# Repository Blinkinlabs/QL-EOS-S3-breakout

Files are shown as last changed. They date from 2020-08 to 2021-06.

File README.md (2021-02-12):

# QL-EOS-S3-breakout

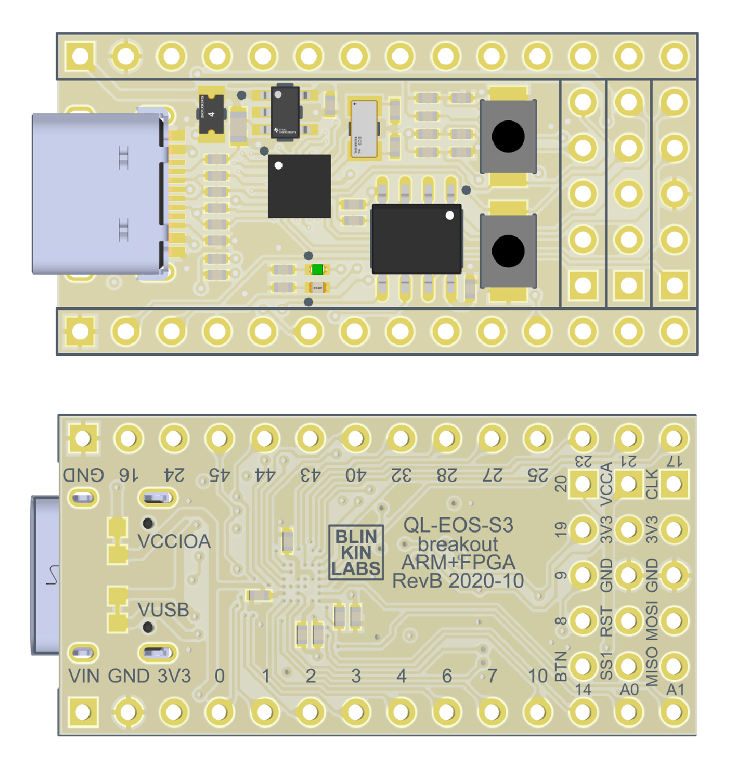
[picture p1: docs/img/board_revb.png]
Pinout guide)


A breadboard-friendly, low part count breakout board for the QuickLogic EOS-S3 ARM/FPGA IC.

Details are in the [Users Guide](https://blinkinlabs.github.io/QL-EOS-S3-breakout/).

Want one? [Sign up](https://docs.google.com/forms/d/e/1FAIpQLSfQSrQm0ui1FXlJnKaiTJos3fivZU6aR2ZEdR-fBZTCpYlu7w/viewform) to be notified when they're available!

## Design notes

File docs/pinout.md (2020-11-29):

# Pinout and Peripherals

## Pinout

Compared to a normal microcontroller, the pins on the QL-EOS-S3 SoC are a little goofy. Similar to a normal microcontroller, it has some hardware GPIO pins that are attached to the ARM core, along with standard peripherals such as UART, and SPI busses, along with an analog port. Unlike a normal microcontroller, however, most of the pins are not connected to the ARM core at all! Instead, they are all connected to the FPGA core, and can be used by writing your own peripherals in Verilog.

Here is a map of all of the fixed pins on the board:

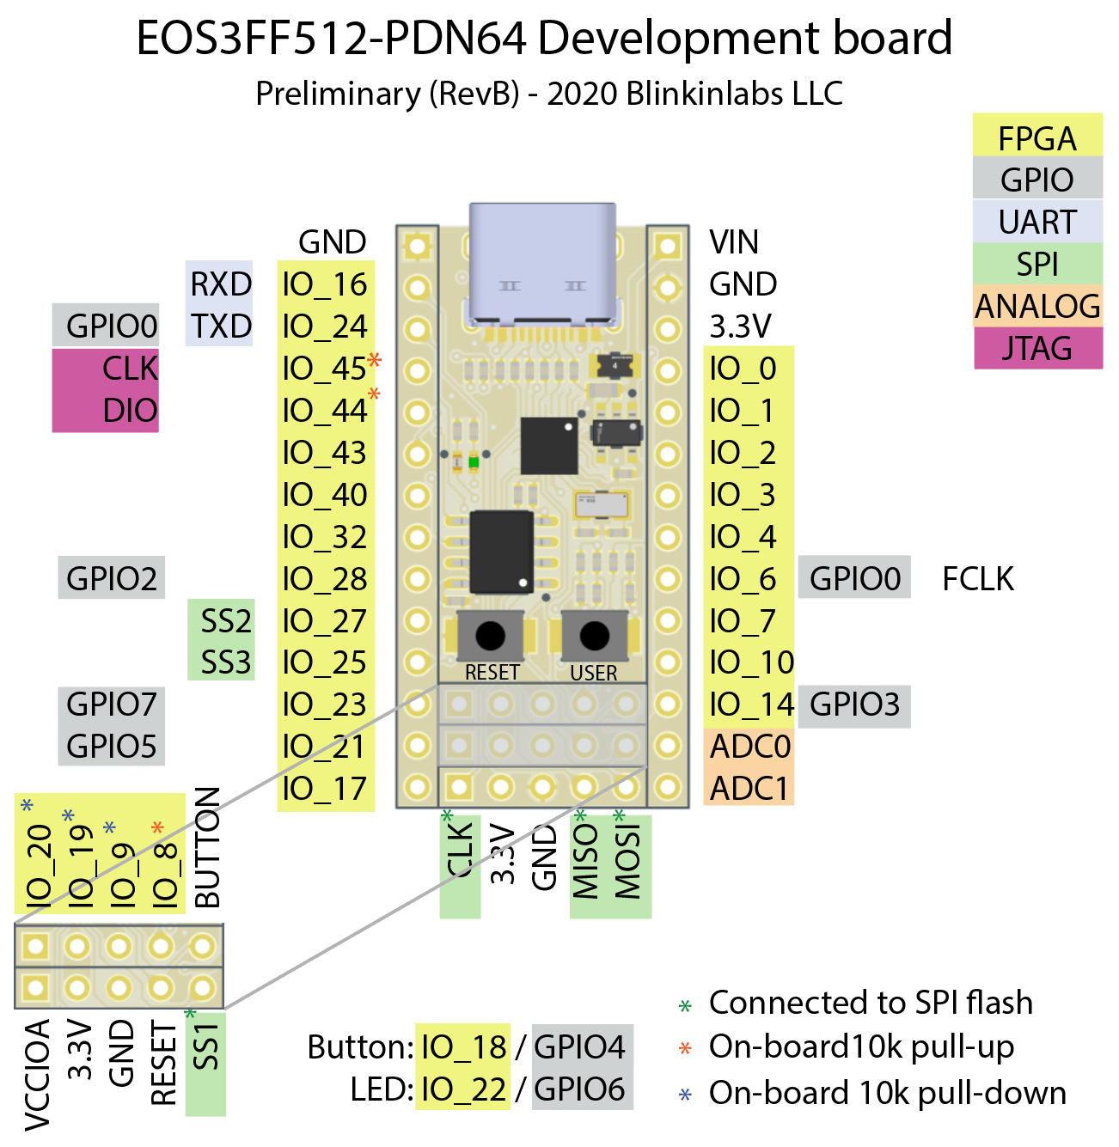
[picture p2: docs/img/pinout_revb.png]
Pinout


All of the pins on the right and left sides of the boards can be used freely. Note that the two JTAG pins (IO_44 and IO_45 on RevB) have on-board pullup resistors to the 3.3V line. The pins in the center section are also possible to use use, however they affect how the SoC boots.

### Use with caution: SPI pins

The SPI pins (CLK, MOSI, MISO, and SS1) are attached to the on-board SPI flash. The CLK, MOSI, and MISO pins can be safely shared with other SPI devices, as long as they do not interfere with the boot process.

### Use with caution: Bootstrap pins

IO_8, IO_9, IO_19, and IO_20 are avaiable as general-purpose IO, however they have 10k pull-down resistors connected to them, and their values have to be logic low at boot time for the microcontroller to turn on correctly.

## Hardware GPIO

The arm core is able to control 8 of the pins (marked GPIO0..7 in the pinout diagram). Here are the steps to use them:

### Step 1: Check that the GPIO is assigned to the correct pin

Each GPIO can be connected to one of two hardware pins. The pin selection is stored in IOMUX_IO_REG_SEL, at 0x40004D60. Here is a table of the available GPIO pin mappings, and the proper one for the breakout board:

| GPIO | Default pin | Alternate pin | Breakout board pin | Notes |
| ---  | --- | --- | --- | --- |
| 0 | IO_6 | IO_24 | IO_6 | |
| 1 | IO_9 | IO_26 | IO_9 | Bootstrap pin |
| 2 | IO_11 | IO_28 | IO_28 | Breakout board uses alternate pin |
| 3 | IO_14 | IO_30 | IO_14 | |
| 4 | IO_18 | IO_31 | IO_18 | Connected to USER BUTTON |
| 5 | IO_21 | IO_36 | IO_21 | |
| 6 | IO_22 | IO_38 | IO_22 | Connected to STATUS LED |
| 7 | IO_23 | IO_45 | IO_23 | |

Only GPIO2 needs to be assigned to the alternate pin, so the following can be used to fully configure the GPIO pin assignments:

    machine.mem32[0x40004D60] = (1<<2)

### Step 2: Configure the pin for GPIO mode

Now that we know the pin that the GPIO is assigned to, the next step is to configure it for GPIO mode, as either an input or output. To do this, write to the IOMUX_PADxx_CTRL register associated with the pad. The address is: 0x40004C00 + 4*(pad number)

Example: Configure pin IO_18 as a GPIO input with pull-up enabled:

    machine.mem32[0x40004C00 + (18*4)] = (0x3<<0) | (0x0<<3) | (1<<8) | (1<<5) | (1<<11) | (0x1<<6)

Example: Configure pin IO_22 as a GPIO output with 4mA drive strength:

    machine.mem32[0x40004C00 + (22*4)] = (0x3<<0) | (0x0<<3) | (1<<8)

### Step 3: Read (or write) to the GPIO

To read from a gpio, use the register MISC_IO_INPUT at 0x40005100. For instance, to read the value of GPIO4 (user button):

    print((machine.mem32[0x40005100] >> 4) & 0x1)

To write a GPIO value, us the register MISC_IO_OUTPUT at 0x40005104. For instance, to set GPIO6 (status led) high:

    machine.mem32[0x40005104] |= (1 << 6)

### Interrupts

Each GPIO pin can be used as a level or edge sensitive interrupt. All GPIO pins share a single interrupt vector.
 
TODO: Example for using interrupts

### Example GPIO library

Here is a barebones GPIO library, written in Micropython:

    class GPIO:
      IOMUX_BASE = 0x40004C00
      IOMUX_IO_REG_SEL = 0x40004D60
      MISC_IO_INPUT = 0x40005100
      MISC_IO_OUTPUT = 0x40005104
      def __init__(self):
        # Configure GPIO pin selects for breakout board
        # Note: Only GPIO2 uses alternate pin setting
        machine.mem32[self.IOMUX_IO_REG_SEL] = (1<<2)
      def write(self, gpio, val):
        if val == 0: # Low
          machine.mem32[self.MISC_IO_OUTPUT] &= ~(1 << gpio)
        else: # High
          machine.mem32[self.MISC_IO_OUTPUT] |= (1 << gpio)
      def read(self, gpio):
        return ((machine.mem32[self.MISC_IO_INPUT] >> gpio) & 0x01)
      def pinmode(self, gpio, mode):
        pads = (6,9,11,14,18,21,22,23)
        if mode == 'input':
          machine.mem32[self.IOMUX_BASE + pads[gpio]*4] = (0x3<<0) | (0x0<<3) | (1<<8) | (1<<5) | (1<<11)
        elif mode == 'input_pullup':
          machine.mem32[self.IOMUX_BASE + pads[gpio]*4] = (0x3<<0) | (0x0<<3) | (1<<8) | (1<<5) | (1<<11) | (0x1<<6)
        elif mode == 'output':
          machine.mem32[self.IOMUX_BASE + pads[gpio]*4] = (0x3<<0) | (0x0<<3) | (1<<8)

And to use it:

    gpio=GPIO()
    gpio.pinmode(6,'output')
    gpio.write(6,1) # turn on LED
    gpio.pinmode(4,'input_pullup')
    gpio.read(4) # read button input

## UART

_TODO_

## SPI Master

SPI Master 1 is connected to the ARM, and available for use. Unfortunately, the technical reference manual is very light on the details, and the SDK drivers are buggy and poorly documented. It appears to be an instantion of a Synopsys DesignWire IP 'DW_apb_ssi'. Because this a commonly used IP block, there are some references to similar hardware:

* [Linux driver](https://github.com/ilbers/linux/blob/master/drivers/spi/spi-dw.h)

_TODO_

## Analog to digital controller

_TODO_

## FPGA

The FPGA is the swiss army knife of peripherals

### Clocks

There are 3 input clocks from the ARM to the FPGA:

| Clock | Name | Max frequency | Notes |
| --- | --- | --- | --- |
| C16 | Sys_Clk0 | ? | General purpose |
| C21 | Sys_Clk1 | ? | General purpose |
| C02 | Sys_Pclk | ? | SPI master APB bus clock (?) |

Sys_Clk0 and Sys_Clk1 are 'general purpose' clocks. Both are fed from dedicated clocks, so configuring them should not intefere with any other ARM peripherals. They can be driven by either the high or low speed system clocks, with a divisor from 0-512. The technical reference manual specifies a default maximum speed of 10MHz, however speeds up to the system clock (72MHz) appear to function well.

Sys_Pclk is fed from C02, which is shared with some other ARM peripherals. It is also available for use, but reconfiguring it might cause problems.

There are 2 output clocks from the FPGA to the ARM:

| Clock | Name | Max frequency | Usage |
| --- | --- | --- | --- |
| C40 | WB_CLK | 10 Mhz | Fabric to Wishbone clock |
| C41 | Sys_Pkfb_Clk | 10 MHz | Fabric to PKFB (packet fifo) clock |

Both of these clocks are special purpose, and should be configured if you are planning to use their associated peripherals.

### IO pads

The FPGA can control all of the IO pads, including a direction function. However, the pads must first be configured by the ARM processor, for both driving source and I/O control functions.

Some of the pads are special clock inputs (TODO: which ones?)

### SPI Master

The FPGA is supposed to be able to interface with the SPI master, for some reason. It's not clear how to do this, or what the intended use case is.

### Communicating with the FPGA

To get the best use out of your FPGA designs, you'll want to talk to them from the ARM core. Here are some of the ways to do so.

#### AHB <-> wishbone bridge

The easiest way to talk to the FPGA is through the AHB<->wishbone bus, which directly maps into the ARM memory space.

| Block | M4 base address | Size |
| --- | --- | --- |
| Fabric (FPGA) | 0x4002_0000 | 128KB |

Transactions must be intiated by the ARM. For bulk data transfer, consider the Packet FIFO interface.

#### SDMA

_TODO_

#### Packet FIFO

There are 4 fifo blocks:

| Block | M4 base address | Size |
| --- | --- | --- |
| RAMFIFO0 (FPGA) | 0x4001_8000 | 4KB |
| RAMFIFO1 (FPGA) | 0x4001_9000 | 4KB |
| RAMFIFO2 (FPGA) | 0x4001_A000 | 4KB |
| RAMFIFO3 (FPGA) | 0x4001_B000 | 4KB |

_TODO_

#### Interrupts

There are 4 interrupt sources from the FPGA to the ARM.

| Intr Num | NVIC Intr | Address | Exception | Priority | Comments |
| --- | --- | --- | --- | --- | --- |
| 20 | 4 | 0x50 | Fabric | Message 0-7 (programmable) | SoC WIC interrupts |

FB_0_INTR, FB_1_INTR, FB_2_INTR, FB_3_INTR

## Other peripherals (I2C, I2S, PDM, FFE, Sensor Manager)

The datasheet and technical reference talk about some other useful peripherals, such as I2C, I2S, and PDM. Unfortunately, these peripherals seem to be attached to the Sensor Manager, and thus not directly accessable to the ARM part. It's unclear if the Sensor Manager is present in the version of the SoC that we have. The Flex Fusion Engine (FFE) is also mentioned, but is likely not enabled in the part variant that we have without some trickery.

Fortunately, this is the kind of task that the FPGA is perfect for. For instance, if you want an I2C bus, or ten, you can design them using Verilog, then use them directly from the ARM core. You're free to make the best possbile peripherals!

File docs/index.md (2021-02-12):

# QL-EOS-S3-breakout

Pinout guide

A breadboard-friendly, low part count breakout board for the QuickLogic EOS-S3 ARM/FPGA IC.

The goals of this project are:

* Low-cost, minimum viable ARM+FPGA design that is breadboard compatable
* Footprint, power, UART pin compatibility with Teensy 3.2.
* All pins on Bank A placed in a group, because they can have their IO voltage set with a reference
* Bootstrap, SPI flash, and reset pins placed in non-breadboardable location to avoid inadvertant interference with application circuit
* Pins with multiple IO functions preferred over FPGA only pins
* Pins in understandable (ascending) order by FPGA IO number, when possible

See the [release PDF](https://raw.githubusercontent.com/Blinkinlabs/QL-EOS-S3-breakout/main/releases/2020-10-06_ql-eos-s3-breakout_RevB.pdf) for the schematic.

Want one? [Sign up](https://forms.gle/7uMRd7YTaTRd96Ph6) to be notified when they are available!

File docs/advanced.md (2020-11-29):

# Advanced topics

## Reprogramming the SPI flash

### Introduction
The EOS-S3 SoC does not have internal nonvolatile memory, so it boots from an external SPI flash. The breakout board has a bootloader pre-installed in the flash memory, which can be used to program the device using it's USB port. However, if the bootloader becomes corrupted for whatever reason, it can be useful to restore the whole SPI flash.

To do this, you'll need a [Teensy](https://www.pjrc.com/store/teensy32.html) with the [spiflash](https://github.com/osresearch/spiflash) firmware loaded.

First, some technical details. This is the flash memory layout that the quickfeather bootloader is expecting:

|Item |Status |Start | Size | End |Start | Size | End |
|----- |---|---:| ---:| ---:  |---:| ---: | ---:|
|bootloader |Used |0x0000_0000| 0x0001_0000| 0x0000_FFFF | 0  | 65,536 |  65,536 |
|bootfpga CRC |Used |0x0001_0000| 8| 0x0001_0007 | 65,536  | 8 |  65,544 |
|appfpga CRC |Future |0x0001_1000| 8| 0x0001_1007 | 69,632  | 8 |  69,640 |
|appffe CRC |Future |0x0001_2000| 8| 0x0001_2007 | 73,728  | 8 |  73,736 |
|M4app CRC |Used |0x0001_3000| 8| 0x0001_3007 | 77,824  | 8 |  77,832 |
|bootloader CRC |Used |0x0001_4000| 8| 0x0001_4007 | 81,920  | 8 |  81,928 |
|bootfpga |Used |0x0002_0000| 0x0002_0000| 0x0003_FFFF | 131,072 | 131,072 | 262,144 |
|appfpga |Future |0x0004_0000| 0x0002_0000| 0x0005_FFFF | 262,144 | 131,072 | 393,216 |
|appffe |Future |0x0006_0000| 0x0002_0000| 0x0007_FFFF | 393,216 | 131,072 | 524,288 |
|M4app |Used |0x0008_0000| 0x0006_E000| 0x000E_DFFF | 524,288 | 450,560 | 974,848 |

The hardware in the SoC only cares about the first section, which contains the bootloader. When it comes out of reset, configuration logic in the SoC reads 32 bits of data from the SPI flash location 0x120, which contains a device ID, the size of the bootloader image, and the desired SPI clock setting. If these are valid, the configuration logic then copies the bootloader into the device SRAM, and then starts the ARM processor.

Once it starts, the bootloader displays a prompt on the UART pins, then waits 5 seconds. If the user button is pressed during these 5 seconds, then it loads the bootfpga image into the FPGA, which allows the user to reprogram the device using the TinyFPGA programmer. If the button is not pressed within 5 seconds, the bootloader attempts to load the user program from the SPI flash into SRAM. It then verifies that the CRC makes (TODO: Does it actually do this?), and if it does, reconfigures the ARM to point to that code, to enter the user program.

The TLDR here is that if we want to write a raw image to the flash, we'll need at least the bootloader, bootloader CRC, bootfpga, andd bootfpga CRC sections to be present. For extra points, we can also preinstall a user app by filling the M4app and M4app CRC sections.

### Step 1: Build the bootloader
First, let's build the bootloader:

    cd ~/ql-eos-s3/qorc-sdk/bl_apps/bl_bootloader/GCC_Project
    make

_TODO: what sets up the 0x120 offset in the bootloader binary?_

### Step 2: Make a flash image
A tool to build a suitable image is included in the [bl apps](https://github.com/Blinkinlabs/bl_apps/blob/main/tools/build_flash_image.py). Using it with the default options will grab the bootloader binary image that we just compiled above, as well as a (for now) precompiled appfpga image:

    cd ~/ql-eos-s3/qorc-sdk/bl_apps/tools
    python3 build_flash_image.py
    added section:bootloader at:0x00000000 size:38228 crc:0x555d0a3e
    added section:bootfpga at:0x00020000 size:75960 crc:0x82fc1983
    Wrote 0xee000 bytes to image.bin

This should create a file called 'image.bin', which we can then load on the SPI flash chip, starting at offset 0.

### Step 3: Flash it
Connect the Teensy to the dev board like so. Be sure to short the 'RST' pin on the board to 'GND', to prevent the SoC from booting:

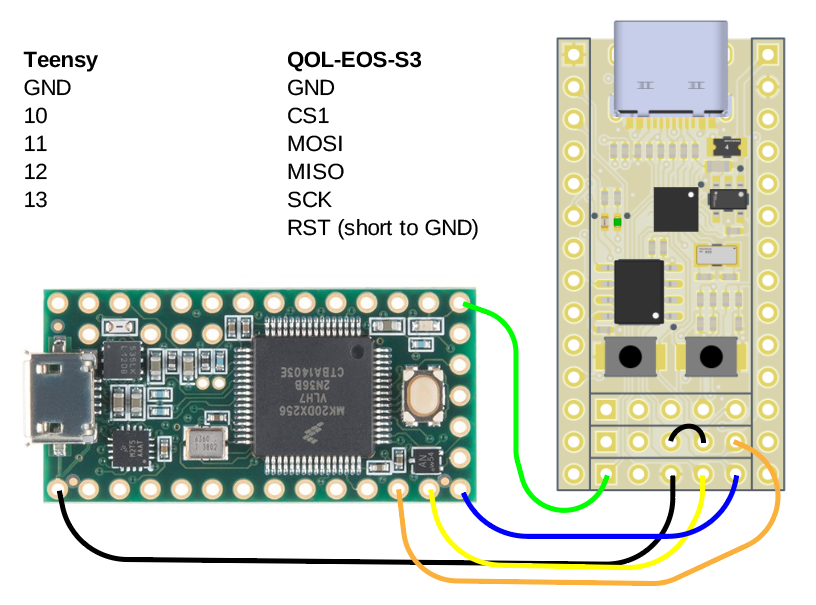
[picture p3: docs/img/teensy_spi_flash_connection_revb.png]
Teensy flash diagram


_TODO: text version of the pin table_

Next, connect both the Teensy and the board to your computer using USB. Use your favorite serial terminal to connect to the Teensy. Issue the 'i' command to check if the SPI flash can be identified:

    i
    C84015C8

_Note: The device ID for the flash on your board may differ, this is for the 2MB version_

Now, tell the Teensy that we want to write EE000 bytes to the SPI flash, starting at offset 0. If the flash image was a different length, use that instead:

    u0 EE0000
    G 00000000 EE0000

_Note: The 'u' will not be echoed to the terminal_

Exit the serial terminal, and then use the PV command to write the image:

    pv image.bin > /dev/ttyACM0

Now, detach the Teensy, then remove the jumper between RST and GND to boot flash image.

## Set the IO pins in Bank A to a different reference voltage
### Introduction
If you need to interface with a device that uses a different logic voltage than 3.3V, it is possible to set the reference voltage for the pins on Bank A.

### Step 1: Cut the VCCIOA trace on the back of the board
On the back side of the board, cut the short copper trace in the middle of the 'VCCIOA' pad. This will disconnect the VCCIOA power line from the on-board 3.3V regulator:
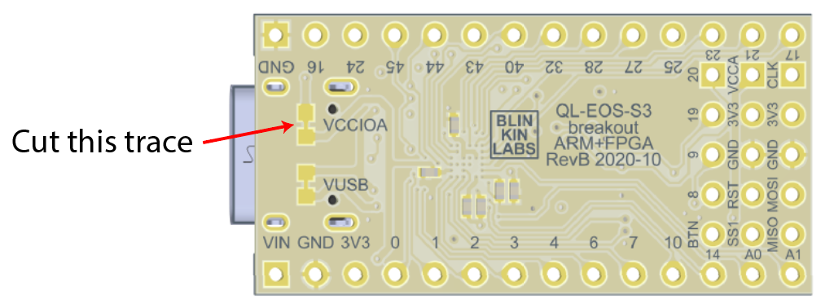
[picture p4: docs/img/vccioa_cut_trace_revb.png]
Cut the VCCIO trace


### Step 2: Provide a 1.71 - 3.6V reference on the VCCA pin
Once the trace has been cut, you'll need to connect an external voltage to the header pin marked 'VCCA'. Then, all of the pins on the right-hand side of the board will be referenced to the external supply:
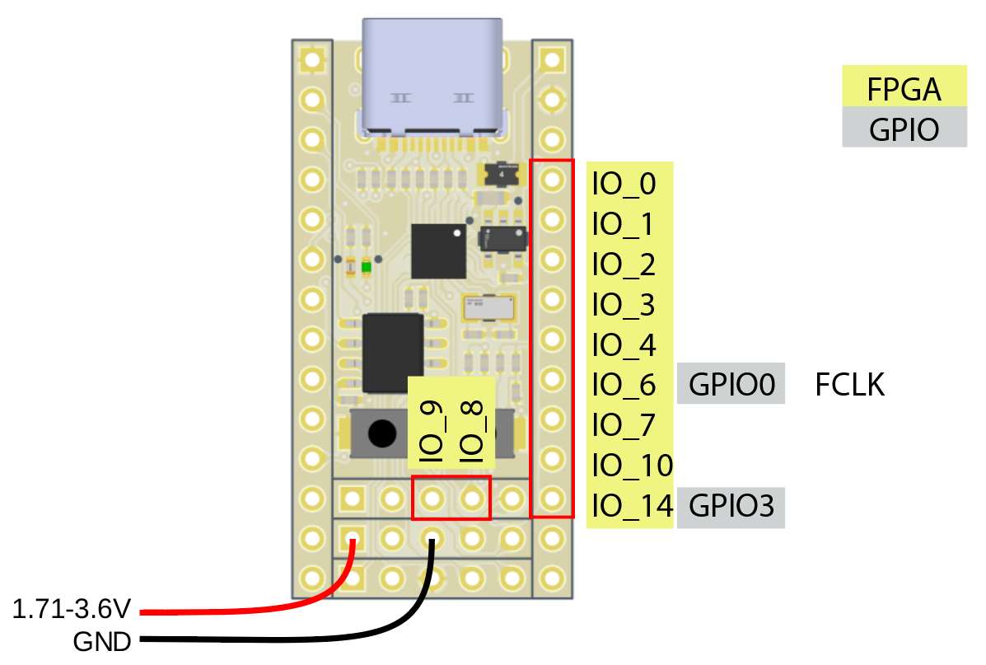
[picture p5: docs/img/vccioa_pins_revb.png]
VCCIOA pins


_Note: The datasheet specifies a range of 1.71-3.6V for safe operation_

## Attach a JTAG debugger
_TODO_

Using JTAG with the RevB board reuqires pulling up both IO_8 and IO_9, and supplying a clock to FCLK. Additionally, the 10k pullups on SWD and SCK may not be present, and would need to be added externally. A future revision will use an alternate JTAG pin mapping, to allow it to be used with the on-board oscillator.

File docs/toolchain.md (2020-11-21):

# Toolchain Setup

## Introduction
This is based on [Quickfeather getting started](https://github.com/QuickLogic-Corp/qorc-sdk#toolchain). There are instructions there for compiling from source.

## Prerequisites
Some prerequisites for a Debian / Ubuntu environment:

    sudo apt install build-essential
    sudo apt remove modemmanager
    sudo usermod -a -G dialout $USER

_Note: If you just added your user to dialout, log out and then back in again to apply the new membership_

Let's attempt to contain everything in a single directory:

    export INSTALL_DIR="$HOME/ql-eos-s3"
    mkdir $INSTALL_DIR
    cd $INSTALL_DIR

## ARM toolchain
First up, get ARM GCC:

    wget https://developer.arm.com/-/media/Files/downloads/gnu-rm/9-2020q2/gcc-arm-none-eabi-9-2020-q2-update-x86_64-linux.tar.bz2
    tar xvjf gcc-arm-none-eabi-9-2020-q2-update-x86_64-linux.tar.bz2 -C $INSTALL_DIR

    export PATH=$INSTALL_DIR/gcc-arm-none-eabi-9-2020-q2-update/bin/:$PATH

## FPGA toolchain
Then Symbiflow:

    wget 'https://github.com/QuickLogic-Corp/quicklogic-fpga-toolchain/releases/download/v1.3.0/Symbiflow_v1.3.0.gz.run'
    bash Symbiflow_v1.3.0.gz.run

    export PATH="$INSTALL_DIR/install/bin:$INSTALL_DIR/install/bin/python:$PATH"
    source "$INSTALL_DIR/conda/etc/profile.d/conda.sh"
    conda activate

And the TinyFPGA bootloader:

    git clone --recursive https://github.com/QuickLogic-Corp/TinyFPGA-Programmer-Application.git

    pip3 install pyserial
    pip3 install tinyfpgab

_Note: Make sure to activate conda in the previous step before using pip3 to install the python eggs_

## SDK
Now for the SDK and Blinkinlabs exmaples:

    git clone --recursive https://github.com/QuickLogic-Corp/qorc-sdk.git

    cd qorc-sdk
    git clone https://github.com/Blinkinlabs/bl_apps.git

# Default enviromnet
To make the tools available in your default environment, add the following to your .bashrc:

    # ARM gcc toolchain
    export PATH=$HOME/ql-eos-s3/gcc-arm-none-eabi-9-2020-q2-update/bin/:$PATH

    # FPGA toolchain for ql-eos-s3
    export INSTALL_DIR="$HOME/ql-eos-s3"
    export PATH="$HOME/ql-eos-s3/install/bin:$HOME/ql-eos-s3/install/bin/python:$PATH"
    source "$HOME/ql-eos-s3/conda/etc/profile.d/conda.sh"
    conda activate

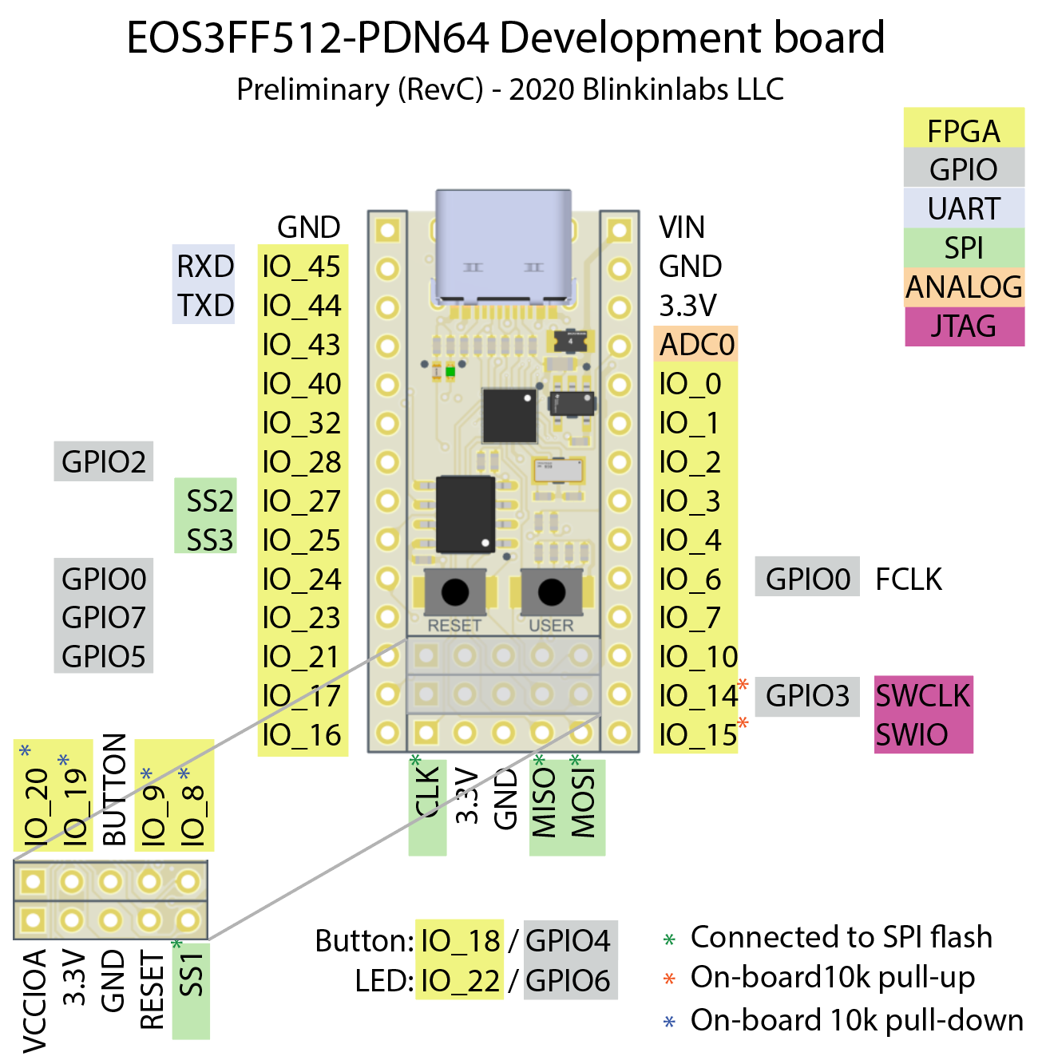
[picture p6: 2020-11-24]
docs/img/pinout_revc.png

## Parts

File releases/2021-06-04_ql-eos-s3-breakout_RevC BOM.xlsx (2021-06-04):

Designator | Comment | Manufacturer | PartNumber | Digi-Key Part Number | LCSC PartNumber | Description | Pins | Quantity | Model:Footprint | Case/Package
C1, C2, C5, C6 | 4.7uF | Murata Electronics North America | GRM155R60J475ME47D | 490-5915-1-ND |  | CAP CER 4.7UF 6.3V X5R 0402 | 2 | 4 |  | 0402
C3, C4 | 12pF | Murata Electronics North America | GRM1555C1E120GA01D | 490-8169-1-ND |  | CAP CER 12PF 25V NP0 0402 | 2 | 2 |  | 0402
C7, C8, C9, C10, C11 | 0.10uF | Murata Electronics North America | GRM152R61A104ME19D | 490-10009-1-ND |  | CAP CER 0.1UF 10V X5R 0402 | 2 | 5 |  | 0402
C12 | 4.7uF | Murata Electronics North America | GRM188R61A475KE15D | 490-10477-1-ND |  | CAP CER 4.7UF 10V X5R 0603 | 2 | 1 |  | 0603
DS1 | SML-P12PTT86 | Rohm |  |  |  | LED GREEN CLEAR 1006 SMD | 2 | 1
DS2 | SMLP12BC7TT86 | Rohm |  |  |  | LED BLUE CLEAR 1006 SMD | 2 | 1
F1 | MF-PSMF050X-2 | Bourns Inc. |  |  |  | PTC RESET FUSE 6V 500MA 0805 | 2 | 1
J1 | TYPE-C-31-M-12 | HRO | TYPE-C-31-M-12 |  |  | USB Connector TYPE-C-31-M-12 Female 16P SMD | 12 | 1 | USB Connector TYPE-C-31-M-12 Female 16P SMD
P1, P2 | Header 14 |  |  |  |  | Header, 14-Pin | 14 | 2 | Connector; Header; 14 Position
P3, P4, P5 | Header 5 |  |  |  |  | Header, 5-Pin | 5 | 3 | Connector; Header; 5 Position
R1, R2 | 5.1k | Panasonic Electronic Components | ERJ-2GEJ512X | P5.1KJCT-ND |  | RES SMD 5.1K OHM 5% 1/10W 0402 | 2 | 2 |  | 0402
R5, R8, R9, R22 | 1.5k | Panasonic Electronic Components | ERJ-2GEJ152X | P1.5KJCT-ND |  | RES SMD 1.5K OHM 5% 1/10W 0402 | 2 | 4 |  | 0402
R6, R7 | 22 | Panasonic Electronic Components | ERJ-2GEJ220X | P22JCT-ND |  | RES SMD 22 OHM 5% 1/10W 0402 | 2 | 2 |  | 0402
R10, R12, R13, R16, R17, R20, R21 | 10k | Panasonic Electronic Components | ERJ-2GEJ103X | P10KJCT-ND |  | RES SMD 10K OHM 5% 1/10W 0402 | 2 | 7 |  | 0402
SW1, SW2 | TS-1185 | XKB | TS-1185 |  |  | Tact Switch, 3x4mm, no alignment pin, turtle style | 2 | 2 | 3x4x2mm Tact Switch, no alignment pin
U1 | QL-EOS-S3 | QuickLogic Corporation | QL-EOS-S3 |  |  | QuickLogicEOS S3 Ultra Low Power multicore MCU | 64 | 1 | BGA, 64-Leads, Body 3.50x3.50mmx0.80mm, Pitch 0.40mm
U2 | TLV73333PDBVR | Texas Instruments |  |  |  | IC REG LINEAR 3.3V 300MA SOT23-5 | 5 | 1
U3 | GD25Q16CTIG | Gigadevice | GD25Q16CTIG |  |  | 16M-bit Serial Flash, 256 Bytes per programmable page, standard, dual, quad SPI | 8 | 1 | SOP, 8-Leads, Body 4.90x3.85mm, Pitch 1.27mm, IPC Medium Density
Y1 | ECS-.327-12.5-34B-TR |  |  |  |  | CRYSTAL 32.7680KHZ 12.5PF SMD | 2 | 1 |  | SMD/SMT

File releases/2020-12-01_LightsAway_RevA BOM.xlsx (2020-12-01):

Designator | Comment | Manufacturer | PartNumber | Digi-Key Part Number | LCSC PartNumber | Description | Pins | Quantity | Model:Footprint | Case/Package
C1, C2, C3 | 10uF | Murata Electronics North America | GRM21BR61C106ME15L | 490-6474-1-ND |  | CAP CER 10UF 16V X5R 0805 | 2 | 3 |  | 0805
J1, J2, J3, J4, J5, J6, J7, J8 | S4B-PH-SM4-TB(LF)(SN) | JST | S4B-PH-SM4-TB(LF)(SN) |  |  | CONN HEADER SMD R/A 4POS 2MM | 6 | 8 | CONN HEADER SMD R/A 4POS 2MM
J9 | Power | Phoenix Contact | 1751248 |  |  | TERM BLK 2POS SIDE ENT 3.5MM PCB | 2 | 1 | TERM BLK 2POS SIDE ENT 3.5MM PCB
J10 | TFP09-2-12B | Unknown/Generic | TFP09-2-12B |  |  | Micro SD Card Connector | 13 | 1 | Micro SD Card Connector
J11 | FTDI |  |  |  |  | Header, 6-Pin | 6 | 1 | Connector; Header; 6 Position
U1, U3 | SN74HCT245PWR | Texas Instruments |  |  |  | Octal Bus Transceivers With 3-State Outputs, PW0020A, LARGE T&R | 20 | 2 | SOP, 20-Leads, Body 6.6x4.5mm, Pitch 0.65mm, IPC High Density
U2 | BL-EOS-BREAKOUT-REVC | Blinkinlabs | QL-EOS-S3-Breakout |  |  |  | 33 | 1

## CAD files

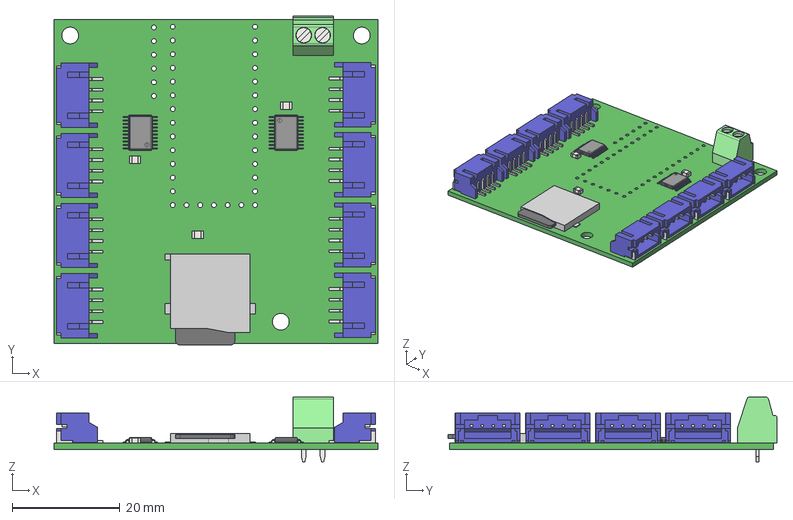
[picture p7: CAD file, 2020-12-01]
releases/2020-12-01_LightsAway_RevA.step
60.0 x 60.9 x 12.0 mm
bohrloch.1 x 2
MKDS_1-2-3_5
BODY_MTC20 x 2
LEAD_MTC20 x 40
TFP09-2-12B_v2
S4B-PH-SM4-TB x 8
Extruded x 9

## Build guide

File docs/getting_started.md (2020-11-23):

# Get Started

## Introduction
The QL-EOS-S3 board is a unique, low-cost microcontroller with a built-in FPGA.

## What you need
Hardware:

* [QL-EOS-S3 breakout board](https://github.com/Blinkinlabs/QL-EOS-S3-breakout)
* USB-C cable
* [3.3V FTDI cable](https://www.sparkfun.com/products/9717) (or other USB-serial converter)
* (optional) [Teensy 3.2](https://www.pjrc.com/store/teensy32.html), for restoring the SPI flash.
* (optional) ARM SWD adapter, such as the [Black magic probe](https://1bitsquared.com/products/black-magic-probe)

Software:

* ARM GCC toolchain, to compile code for the Cortex M4 processor
* Symbiflow toolchain, for generating FPGA bitstreams
* The QORC Software Development Kit
* Blinkinlabs example projects

## Installation

### Step 1: Install the toolchain
Follow the [toolchain setup](toolchain.md) instructions

### Step 2: Build an example project
Test a project that uses both the ARM and FPGA toolchains:

    cd ~/ql-eos-s3/qorc-sdk/bl_apps/bl_helloworldhw/GCC_Project
    make

### Step 3: Connect to the board
Connect your board to your computer using a USB cable. Next, connect an FTDI cable:

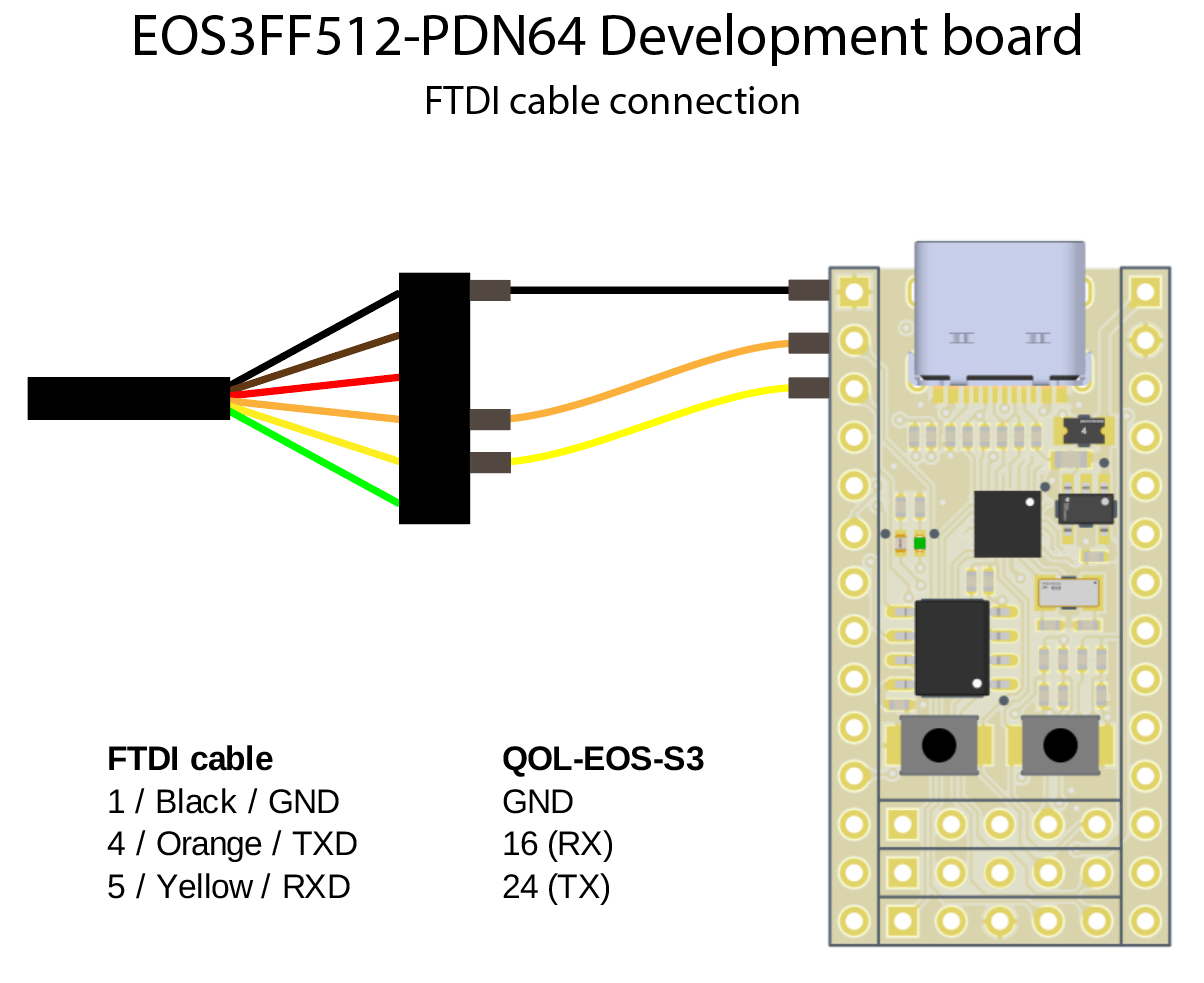
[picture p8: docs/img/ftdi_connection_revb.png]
FTDI connection


Open your favorite serial terminal, and connect to the FTDI serial port with 115200,8N1 setting. Press the reset button on the board (the one closest to the SPI flash chip). The device should send a prompt:

    ##########################
    Blinkinlabs QL-EOS-S3 Breakout Bootloader
    SW Version: qorc-sdk/qf-apps/qf_bootloader(v2) (GCC)
    Nov 11 2020 00:29:45
    ##########################

As soon as you see the prompt, press and hold the user button (the one furthest from the SPI flash chip). The device will then go into bootloader mode, and send a prompt:

    User button pressed: switch to download mode
    FPGA Programmed
    Presss Reset button after flashing ..

If instead you see a message 'User button not pressed: proceeding to load application', just press reset, and try again.

### Step 4: Upload the example project
And try uploading it to the board:

    python3 ~/ql-eos-s3/TinyFPGA-Programmer-Application/tinyfpga-programmer-gui.py --m4app output/bin/bl_helloworldhw.bin --reset
    CLI mode
    ports =  ['/dev/ttyACM0 (QuickFeather)'] 1
    Using port  /dev/ttyACM0 (QuickFeather)
    Programming m4 application with  bl_helloworldhw.bin
    Erasing designated flash pages
    Erase  64.0 KiB ( 0xd8 ) at  0x80000
    Erase  32.0 KiB ( 0x52 ) at  0x90000
    Erase  4.0 KiB ( 0x20 ) at  0x98000
    Writing  binary
    Write  102172  bytes
    [XXXXXXXXXXXXXXXXXXXXXXXXXXXXXXXXXXXXXXXXXXXXXXXXX]
    Verifying  binary
    FastREAD 0x0B ( 102172 )
    [XXXXXXXXXXXXXXXXXXXXXXXXXXXXXXXXXXXXXXXXXXXXXXXXX]
    Success: read_back == data
    Writing metadata
    Erasing designated flash pages
    Erase  4.0 KiB ( 0x20 ) at  0x13000
    Writing  metadata
    Write  8  bytes
    [X]                                               ]
    Verifying  metadata
    FastREAD 0x0B ( 8 )
    [X]                                               ]
    Success: read_back == data
    Reset the device
    boot sent

On the serial terminal, the board should send progress updates:

    Addr: 0x00080000
    Erase 64 KBytes() .. done
    Addr: 0x00090000
    Erase 32 KBytes() .. done
    Addr: 0x00098000
    Erase 4 KBytes() .. done
    Addr: 0x00013000
    Erase 4 KBytes() .. done

And once it's finished, it will automatically restart:

    ##########################
    Blinkinlabs QL-EOS-S3 Breakout Bootloader
    SW Version: qorc-sdk/qf-apps/qf_bootloader(v2) (GCC)
    Nov 11 2020 00:29:45
    ##########################

    User button not pressed: proceeding to load application

    ##########################
    Quicklogic QuickFeather Standalone FPGA
    SW Version: qorc-sdk/qf_apps/qf_helloworldhw
    Nov 18 2020 18:01:17
    ##########################

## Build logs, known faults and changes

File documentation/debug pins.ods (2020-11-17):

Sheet: UART, SPI Flash, SWD connections
UART console
FTDI cable | QOL-EOS-S3
1 / Black / GND | GND
5 / Orange / TXD | 16 (RX)
6 / Yellow / RXD | 24 (TX)
SPI flash programming
Teensy | QOL-EOS-S3
GND | GND
10 | CS1
11 | MOSI
12 | MISO
13 | SCK
 | RST (short to GND)
20-pin SWD
QOL-EOS-S3 | 10-pin cortex | 20-pin JTAG/cortex | Notes
GND | 3 / GND | 4 / GND
3.3V | 1 / Vtref | 2 / Vcc | optional
45 (SWD_CLK) | 4 / SWDCLK | 9 / SWDCLK
44 (SWD_IO) | 2 / SWDIO | 7 / SWDIO
Reset | 10 / nRESET | 15 / RESET | optional

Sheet: Debug pins
Debug pin availability
SWD
signal | pad1 | pad2
SW_DP_CLK | 14 / yes | 45 / yes
SW_DP_IO | 15 / no | 44 / yes
Note: Selection of pad1 / pad2 done at boot by IO_8 bootstrap, unable to change?
Debug monitor
signal | pad1 | pad2 | pad3 | special function
debug_mon[0] | 2 / yes | 18 / yes (button) | 34 / yes (spi_mst_clk)
debug_mon[1] | 4 / yes | 21 / yes | 35 / no
debug_mon[2] | 5 / no | 22 / yes (user_led) | 37 / yes (PU_CTRL_USBP)
debug_mon[3] | 6 / yes | 26 / no | 38 / yes (SPI_MST_MOSI)
debug_mon[4] | 7 / yes | 27 / yes | 39 / yes (SPI_MST_SS1)
debug_mon[5] | 11 / no | 28 / yes | 40 / yes
debug_mon[6] | 12 / no | 32 / yes | 41 / yes (USB_D_N) | Clock C30 and C32 monitor output
debug_mon[7] | 13 / no | 33 / no | 42 / yes (USB_D_P) | Clock C00 ( SPI Slave Clk ), C01, C02, C08x4, C08x1, C09, C10, C11, CS ( SWD Clk ), C19, C20, C21, C23, C31 monitor output
Single wire viewer (SWV)
pad | available?
7 | yes
10 | yes
13 | no
18 | yes (conflict with user button)
23 | yes
25 | yes
36 | yes (conflict with spi_mst_miso)
42 | yes (conflict with usb_d_p)

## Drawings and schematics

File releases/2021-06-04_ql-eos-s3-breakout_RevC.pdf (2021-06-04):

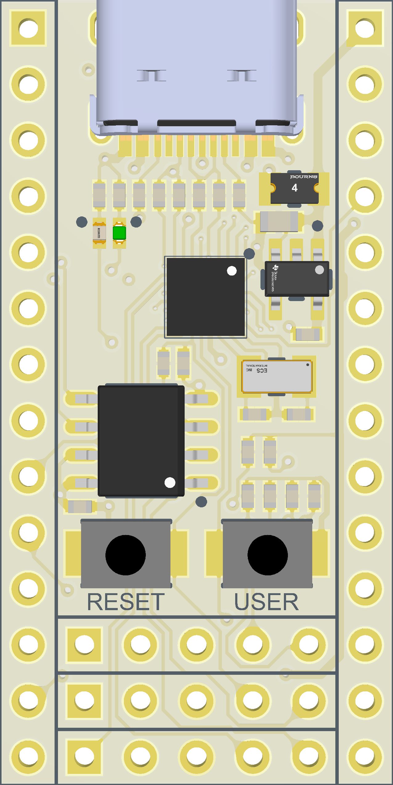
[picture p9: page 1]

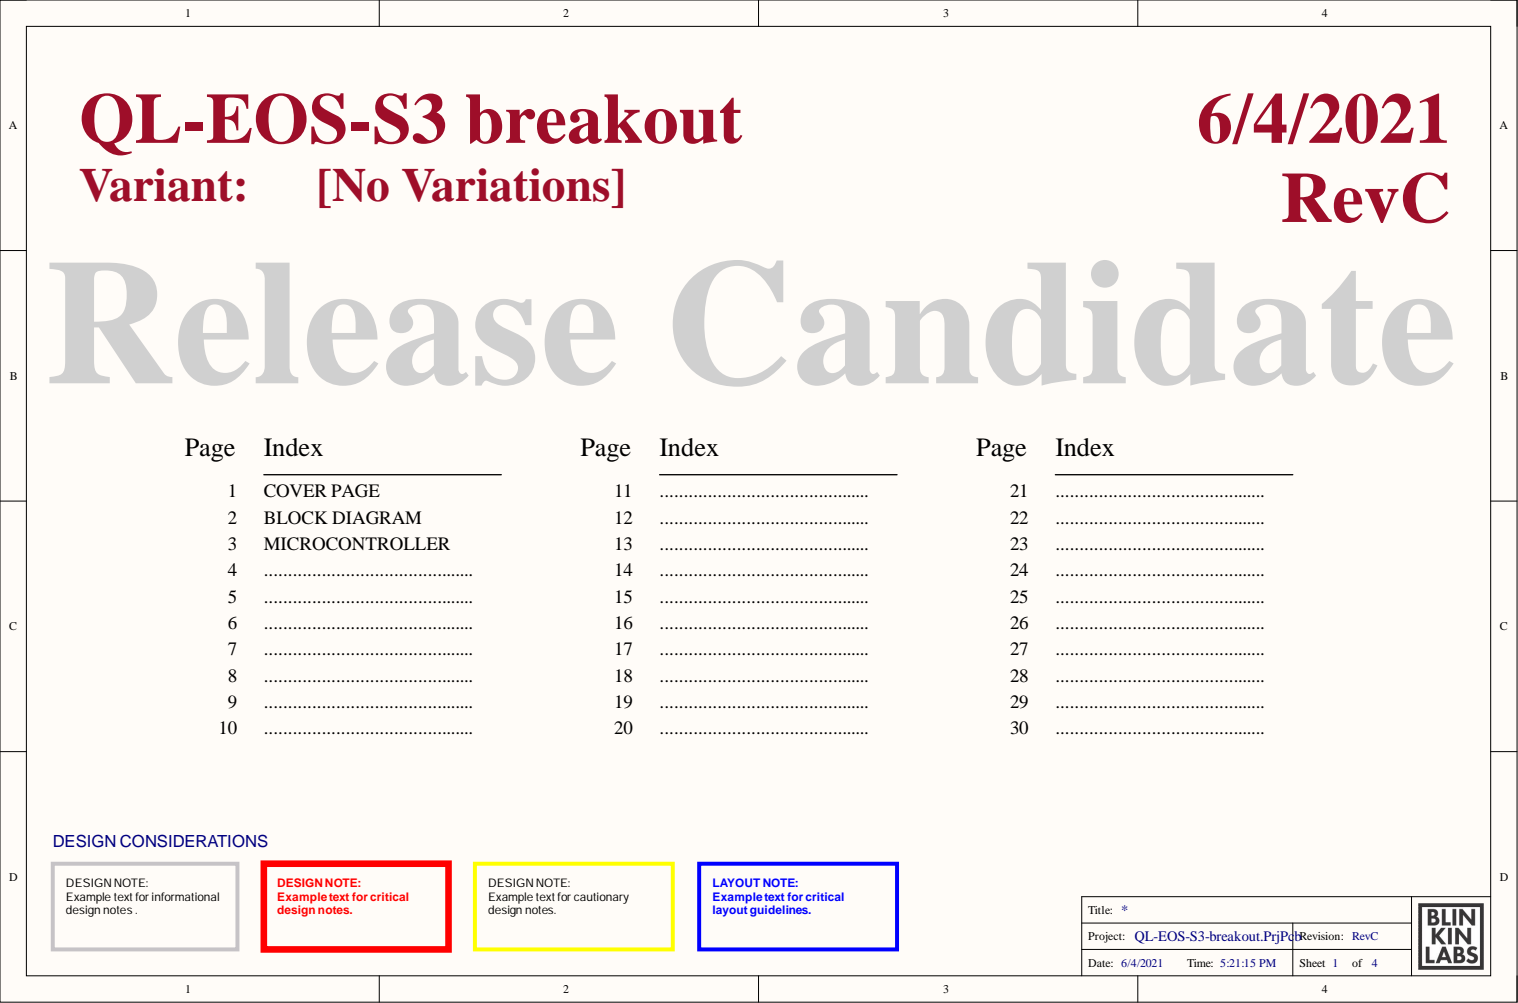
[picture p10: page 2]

DESIGN NOTE:
Example text for informational
design notes .

Example text for critical
design notes.

Example text for cautionary

LAYOUT NOTE:
layout guidelines.

QL-EOS-S3-breakout.PrjPcb

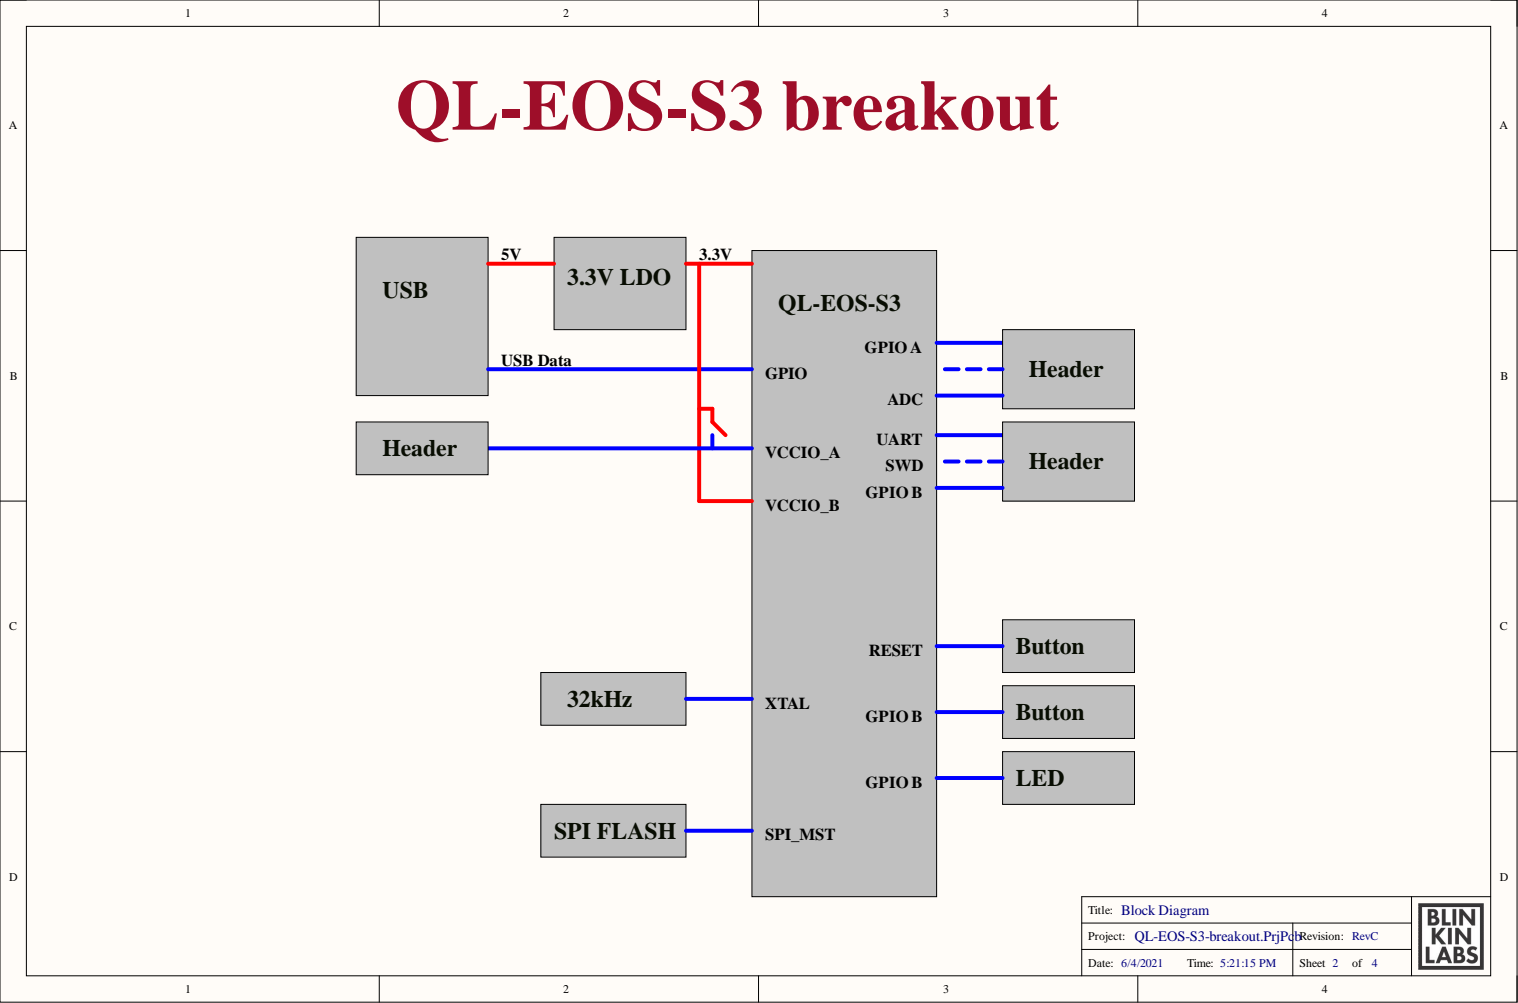
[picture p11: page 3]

QL-EOS-S3-breakout.PrjPcb

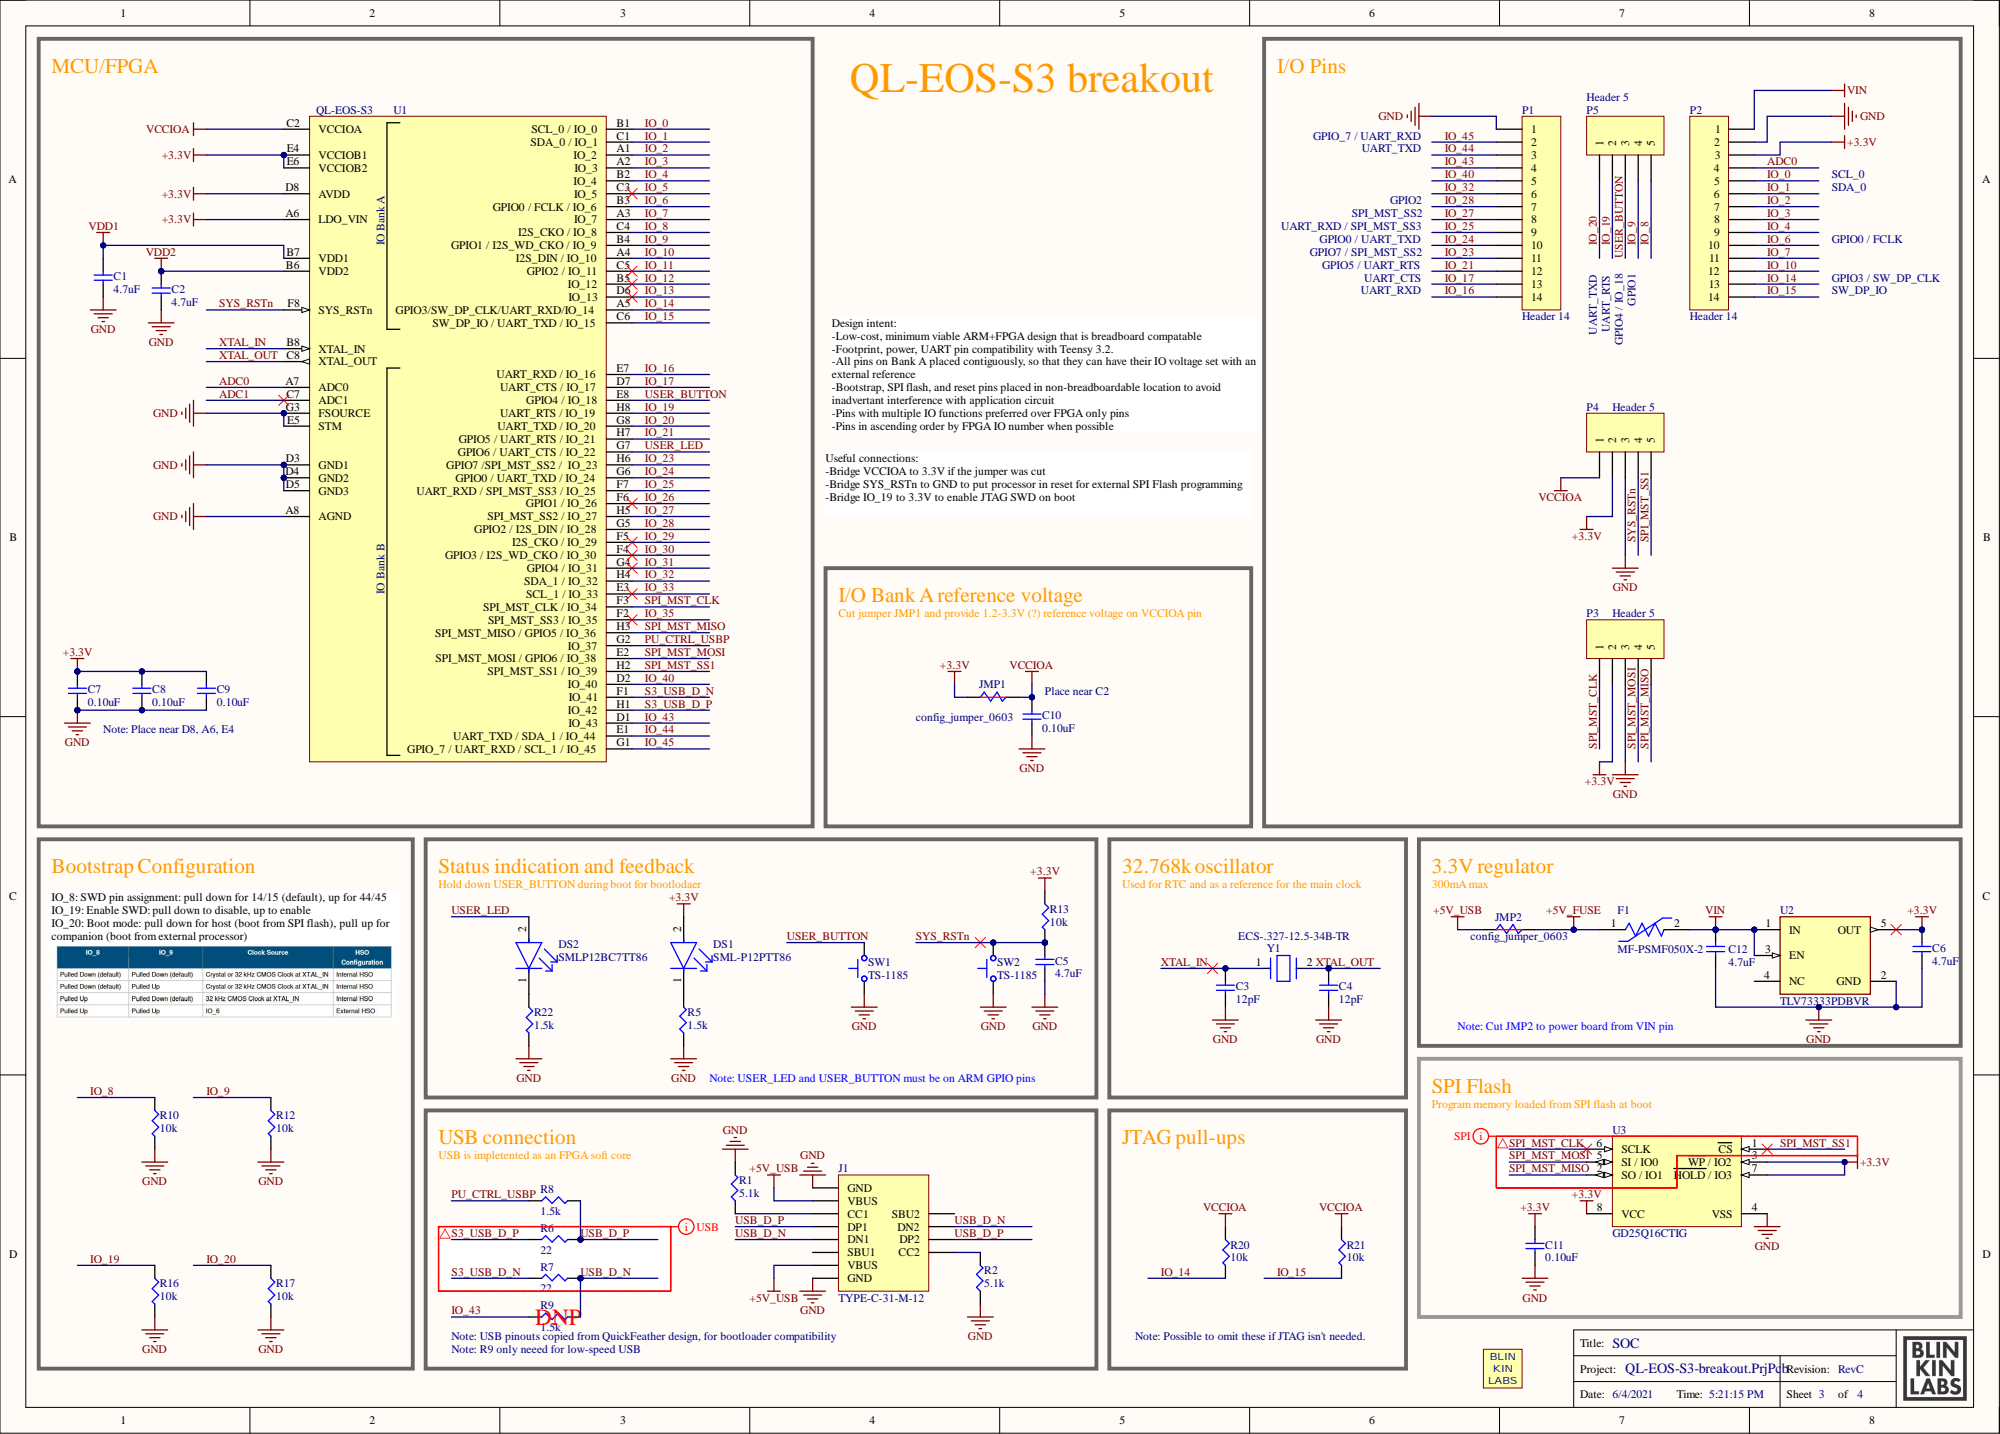
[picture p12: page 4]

IO Bank A IO Bank B

e Cut jumper JMP1 and provide 1.2-3.3V (?) reference v

mA max Note: Cu

ted as an FPG

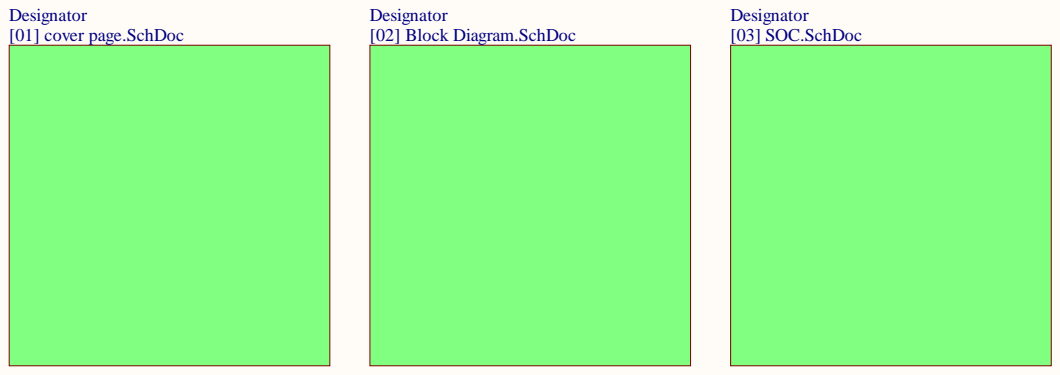
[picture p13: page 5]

QL-EOS-S3-breakout.PrjPcb

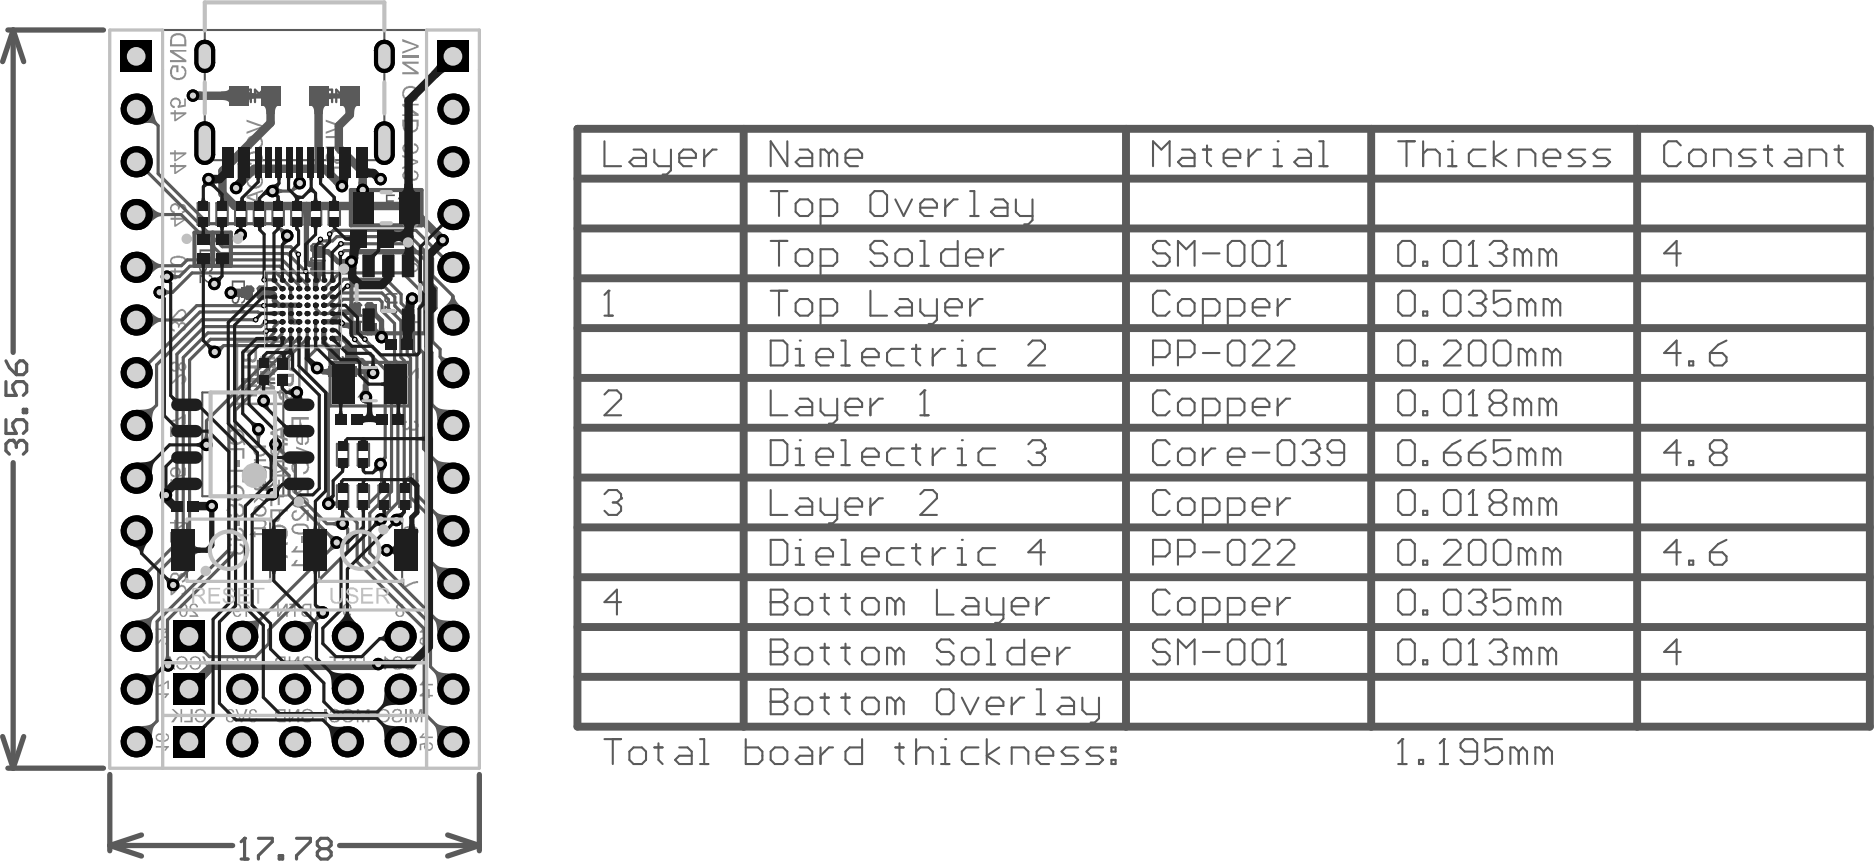
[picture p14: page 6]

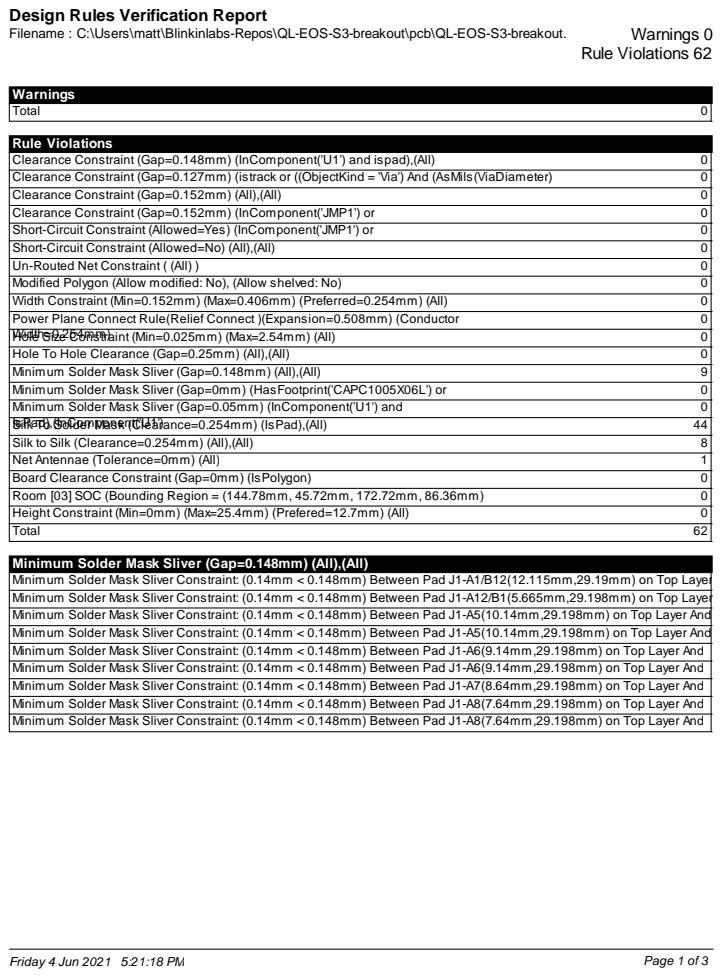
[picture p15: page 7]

Design Rules Verification Report

Rule Violations
Power Plane Connect Rule(Relief Connect )(Expansion=0.508mm) (Conductor
Width=0.254mm)
Minimum Solder Mask Sliver (Gap=0.05mm) (InComponent('U1') and
IsPad),(InComponent('U1')

Minimum Solder Mask Sliver (Gap=0.148mm) (All),(All)
Minimum Solder Mask Sliver Constraint: (0.14mm < 0.148mm) Between Pad J1-A1/B12(12.115mm,29.19mm) on Top Layer
Minimum Solder Mask Sliver Constraint: (0.14mm < 0.148mm) Between Pad J1-A12/B1(5.665mm,29.198mm) on Top Layer
Minimum Solder Mask Sliver Constraint: (0.14mm < 0.148mm) Between Pad J1-A5(10.14mm,29.198mm) on Top Layer And
Minimum Solder Mask Sliver Constraint: (0.14mm < 0.148mm) Between Pad J1-A6(9.14mm,29.198mm) on Top Layer And
Minimum Solder Mask Sliver Constraint: (0.14mm < 0.148mm) Between Pad J1-A7(8.64mm,29.198mm) on Top Layer And
Minimum Solder Mask Sliver Constraint: (0.14mm < 0.148mm) Between Pad J1-A8(7.64mm,29.198mm) on Top Layer And

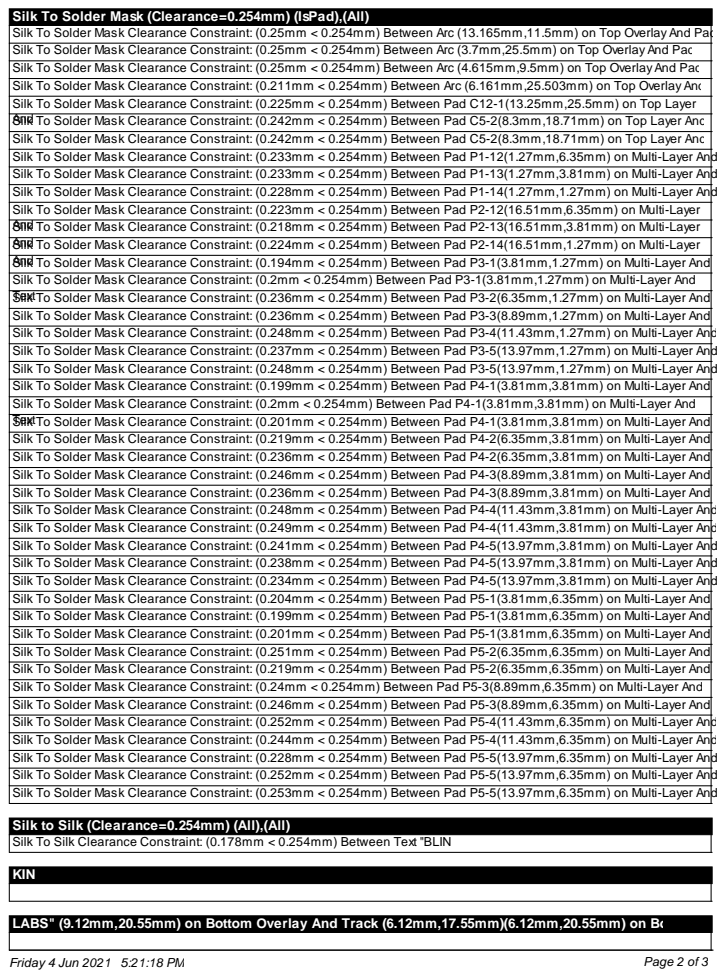
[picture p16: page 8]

Silk To Solder Mask (Clearance=0.254mm) (IsPad),(All)
Silk To Solder Mask Clearance Constraint: (0.25mm < 0.254mm) Between Arc (13.165mm,11.5mm) on Top OverlayAnd Pad
Silk To Solder Mask Clearance Constraint: (0.25mm < 0.254mm) Between Arc (3.7mm,25.5mm) on Top OverlayAnd Pad
Silk To Solder Mask Clearance Constraint: (0.25mm < 0.254mm) Between Arc (4.615mm,9.5mm) on Top OverlayAnd Pad
Silk To Solder Mask Clearance Constraint: (0.211mm < 0.254mm) Between Arc (6.161mm,25.503mm) on Top OverlayAnd
Silk To Solder Mask Clearance Constraint: (0.225mm < 0.254mm) Between Pad C12-1(13.25mm,25.5mm) on Top Layer
ASinldk To Solder Mask Clearance Constraint: (0.242mm < 0.254mm) Between Pad C5-2(8.3mm,18.71mm) on Top Layer And
Silk To Solder Mask Clearance Constraint: (0.242mm < 0.254mm) Between Pad C5-2(8.3mm,18.71mm) on Top Layer And
Silk To Solder Mask Clearance Constraint: (0.233mm < 0.254mm) Between Pad P1-12(1.27mm,6.35mm) on Multi-Layer And
Silk To Solder Mask Clearance Constraint: (0.233mm < 0.254mm) Between Pad P1-13(1.27mm,3.81mm) on Multi-Layer And
Silk To Solder Mask Clearance Constraint: (0.228mm < 0.254mm) Between Pad P1-14(1.27mm,1.27mm) on Multi-Layer And
Silk To Solder Mask Clearance Constraint: (0.223mm < 0.254mm) Between Pad P2-12(16.51mm,6.35mm) on Multi-Layer
ASinldk To Solder Mask Clearance Constraint: (0.218mm < 0.254mm) Between Pad P2-13(16.51mm,3.81mm) on Multi-Layer
ASinldk To Solder Mask Clearance Constraint: (0.224mm < 0.254mm) Between Pad P2-14(16.51mm,1.27mm) on Multi-Layer
ASinldk To Solder Mask Clearance Constraint: (0.194mm < 0.254mm) Between Pad P3-1(3.81mm,1.27mm) on Multi-Layer And
Silk To Solder Mask Clearance Constraint: (0.2mm < 0.254mm) Between Pad P3-1(3.81mm,1.27mm) on Multi-Layer And
Silk To Solder Mask Clearance Constraint: (0.236mm < 0.254mm) Between Pad P3-3(8.89mm,1.27mm) on Multi-Layer And
Silk To Solder Mask Clearance Constraint: (0.248mm < 0.254mm) Between Pad P3-4(11.43mm,1.27mm) on Multi-Layer And
Silk To Solder Mask Clearance Constraint: (0.237mm < 0.254mm) Between Pad P3-5(13.97mm,1.27mm) on Multi-Layer And
Silk To Solder Mask Clearance Constraint: (0.248mm < 0.254mm) Between Pad P3-5(13.97mm,1.27mm) on Multi-Layer And
Silk To Solder Mask Clearance Constraint: (0.199mm < 0.254mm) Between Pad P4-1(3.81mm,3.81mm) on Multi-Layer And
Silk To Solder Mask Clearance Constraint: (0.2mm < 0.254mm) Between Pad P4-1(3.81mm,3.81mm) on Multi-Layer And
Silk To Solder Mask Clearance Constraint: (0.219mm < 0.254mm) Between Pad P4-2(6.35mm,3.81mm) on Multi-Layer And
Silk To Solder Mask Clearance Constraint: (0.236mm < 0.254mm) Between Pad P4-2(6.35mm,3.81mm) on Multi-Layer And
Silk To Solder Mask Clearance Constraint: (0.246mm < 0.254mm) Between Pad P4-3(8.89mm,3.81mm) on Multi-Layer And
Silk To Solder Mask Clearance Constraint: (0.236mm < 0.254mm) Between Pad P4-3(8.89mm,3.81mm) on Multi-Layer And
Silk To Solder Mask Clearance Constraint: (0.248mm < 0.254mm) Between Pad P4-4(11.43mm,3.81mm) on Multi-Layer And
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

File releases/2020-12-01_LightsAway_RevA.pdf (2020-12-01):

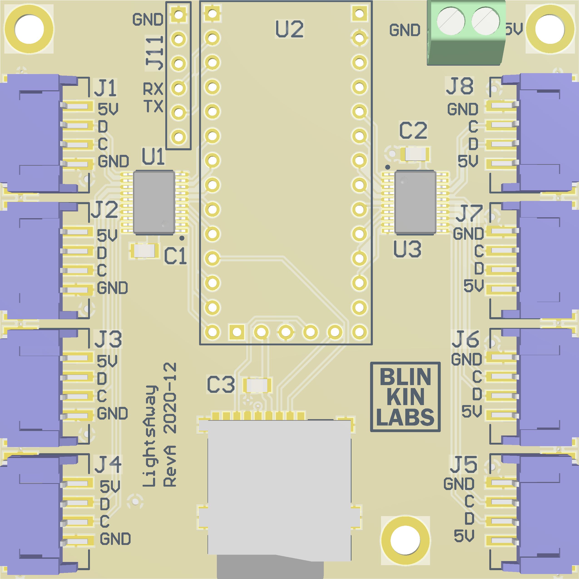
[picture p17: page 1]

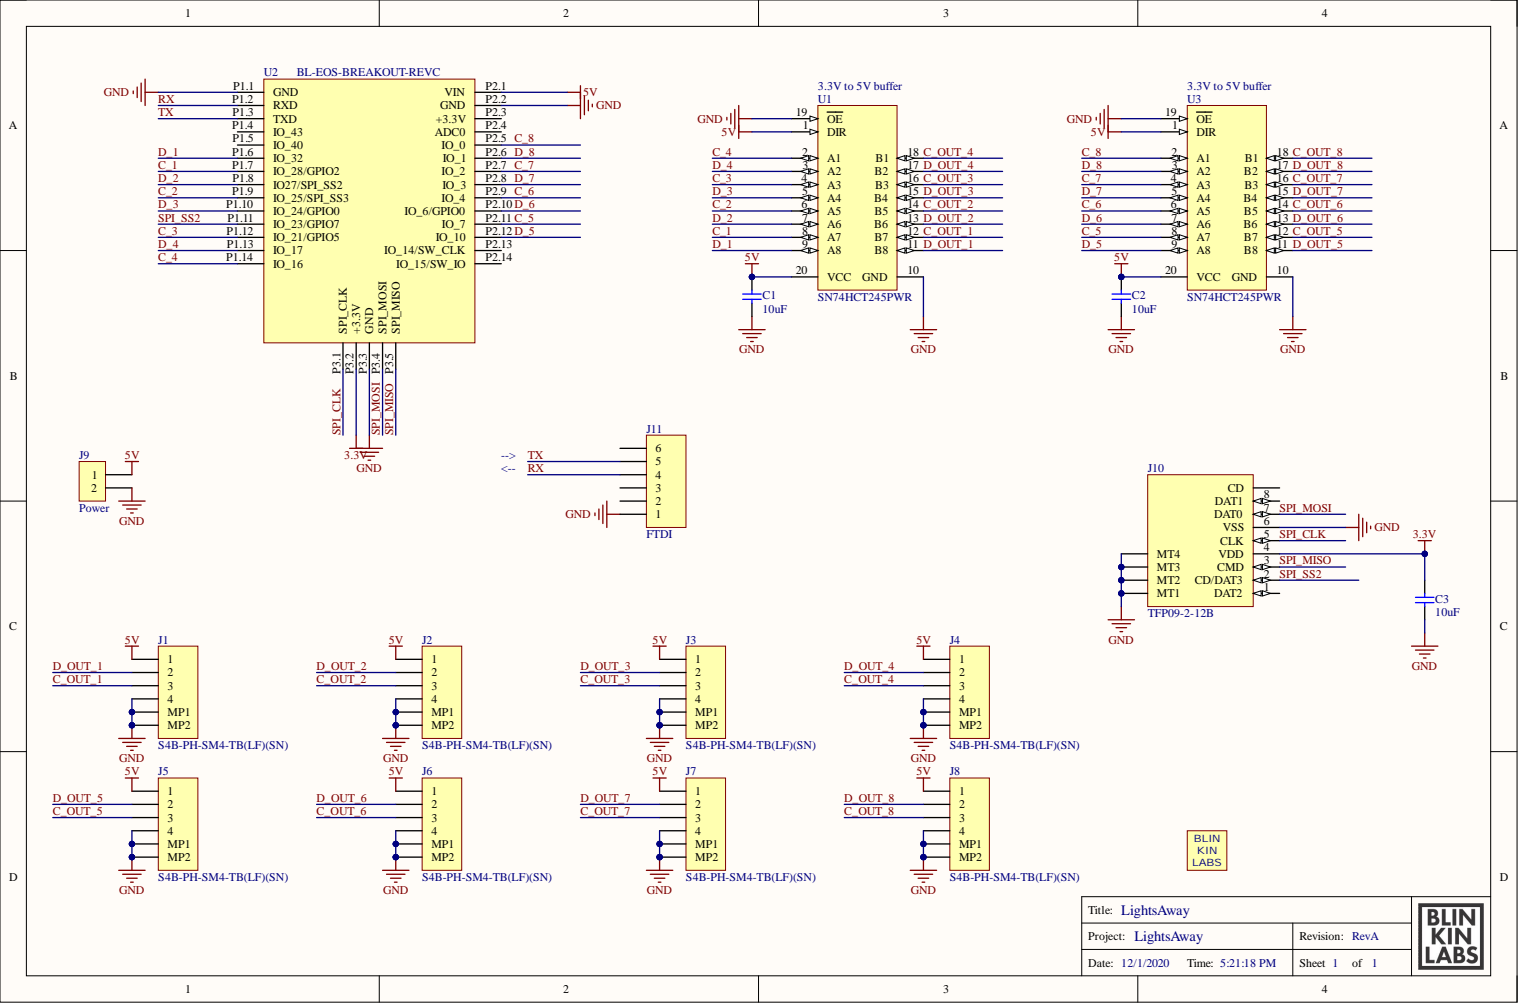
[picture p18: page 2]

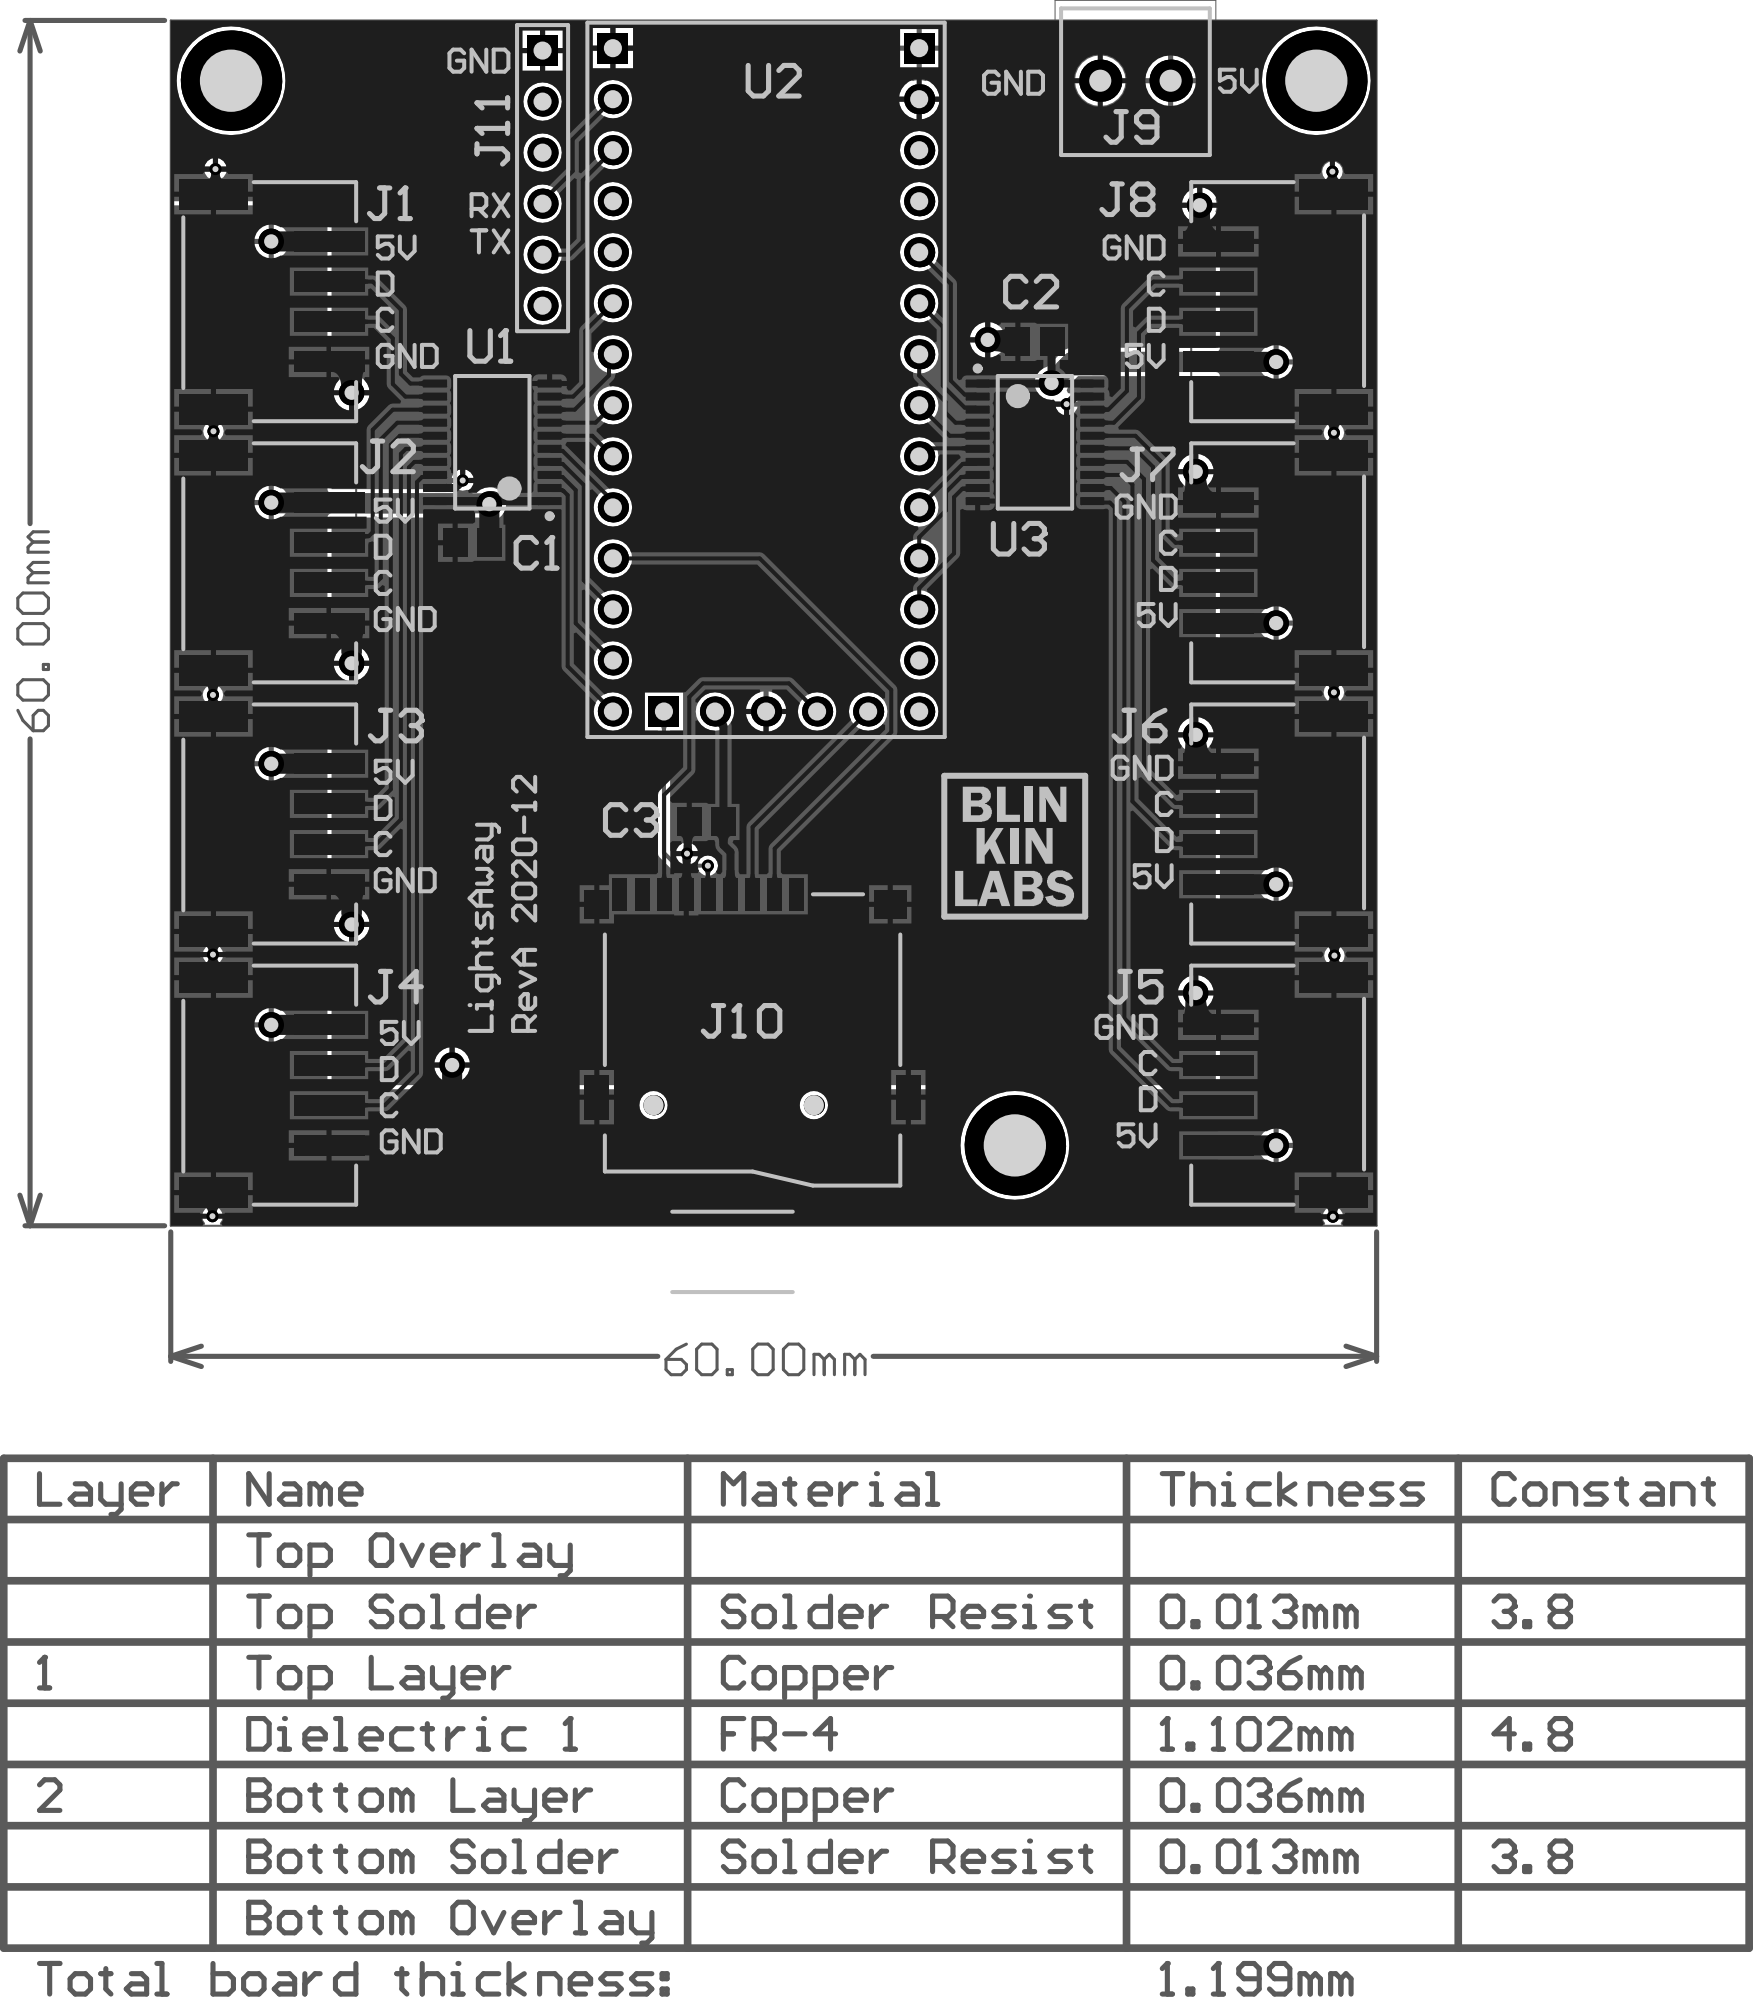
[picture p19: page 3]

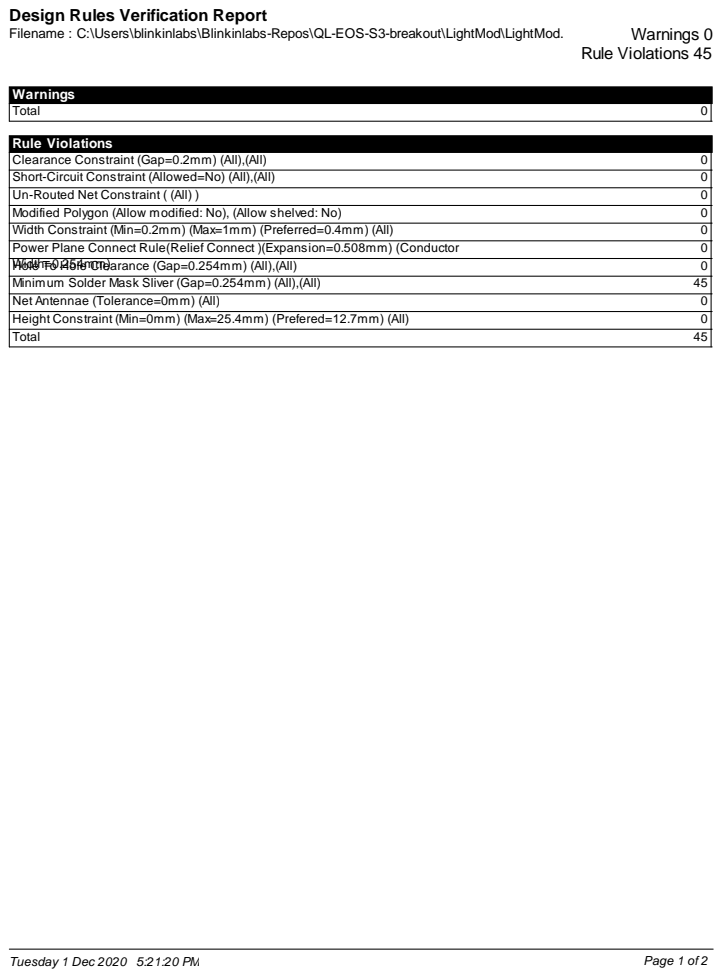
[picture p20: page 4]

Design Rules Verification Report

Rule Violations
Power Plane Connect Rule(Relief Connect )(Expansion=0.508mm) (Conductor
Width=0.254mm)


Minimum Solder Mask Sliver (Gap=0.254mm) (All),(All)
Minimum Solder Mask Sliver Constraint: (0.197mm < 0.254mm) Between Pad J10-1(31.15mm,16.5mm) on Top Layer And
Minimum Solder Mask Sliver Constraint: (0.197mm < 0.254mm) Between Pad J10-2(30.05mm,16.5mm) on Top Layer And
Minimum Solder Mask Sliver Constraint: (0.197mm < 0.254mm) Between Pad J10-3(28.95mm,16.5mm) on Top Layer And
Minimum Solder Mask Sliver Constraint: (0.197mm < 0.254mm) Between Pad J10-4(27.85mm,16.5mm) on Top Layer And
Minimum Solder Mask Sliver Constraint: (0.197mm < 0.254mm) Between Pad J10-5(26.75mm,16.5mm) on Top Layer And
Minimum Solder Mask Sliver Constraint: (0.197mm < 0.254mm) Between Pad J10-6(25.65mm,16.5mm) on Top Layer And
Minimum Solder Mask Sliver Constraint: (0.197mm < 0.254mm) Between Pad J10-7(24.55mm,16.5mm) on Top Layer And
Minimum Solder Mask Sliver Constraint: (0.248mm < 0.254mm) Between Pad J10-8(23.45mm,16.5mm) on Top Layer And
Minimum Solder Mask Sliver Constraint: (0.1mm < 0.254mm) Between Pad J10-CD(22.35mm,16.5mm) on Top Layer And
PaMindimum Solder Mask Sliver Constraint: (0.047mm < 0.254mm) Between Pad U1-1(18.85mm,36.075mm) on Top Layer And
Minimum Solder Mask Sliver Constraint: (0.047mm < 0.254mm) Between Pad U1-10(18.85mm,41.925mm) on Top Layer
Minimum Solder Mask Sliver Constraint: (0.047mm < 0.254mm) Between Pad U1-3(18.85mm,37.375mm) on Top Layer And
Minimum Solder Mask Sliver Constraint: (0.047mm < 0.254mm) Between Pad U1-4(18.85mm,38.025mm) on Top Layer And
Minimum Solder Mask Sliver Constraint: (0.047mm < 0.254mm) Between Pad U1-5(18.85mm,38.675mm) on Top Layer And
Minimum Solder Mask Sliver Constraint: (0.047mm < 0.254mm) Between Pad U1-6(18.85mm,39.325mm) on Top Layer And
Minimum Solder Mask Sliver Constraint: (0.047mm < 0.254mm) Between Pad U1-7(18.85mm,39.975mm) on Top Layer And
Minimum Solder Mask Sliver Constraint: (0.047mm < 0.254mm) Between Pad U1-8(18.85mm,40.625mm) on Top Layer And
Minimum Solder Mask Sliver Constraint: (0.047mm < 0.254mm) Between Pad U3-1(40.15mm,41.925mm) on Top Layer And
Minimum Solder Mask Sliver Constraint: (0.047mm < 0.254mm) Between Pad U3-10(40.15mm,36.075mm) on Top Layer
Minimum Solder Mask Sliver Constraint: (0.047mm < 0.254mm) Between Pad U3-3(40.15mm,40.625mm) on Top Layer And
Minimum Solder Mask Sliver Constraint: (0.047mm < 0.254mm) Between Pad U3-4(40.15mm,39.975mm) on Top Layer And
Minimum Solder Mask Sliver Constraint: (0.047mm < 0.254mm) Between Pad U3-5(40.15mm,39.325mm) on Top Layer And
Minimum Solder Mask Sliver Constraint: (0.047mm < 0.254mm) Between Pad U3-6(40.15mm,38.675mm) on Top Layer And
Minimum Solder Mask Sliver Constraint: (0.047mm < 0.254mm) Between Pad U3-7(40.15mm,38.025mm) on Top Layer And
Minimum Solder Mask Sliver Constraint: (0.047mm < 0.254mm) Between Pad U3-8(40.15mm,37.375mm) on Top Layer And

Mnindimum Solder Mask Sliver Constraint: (0.047mm < 0.254mm) Between Pad U1-11(13.15mm,41.925mm) on Top Layer
Mnindimum Solder Mask Sliver Constraint: (0.047mm < 0.254mm) Between Pad U1-12(13.15mm,41.275mm) on Top Layer
Mnindimum Solder Mask Sliver Constraint: (0.047mm < 0.254mm) Between Pad U1-13(13.15mm,40.625mm) on Top Layer
Mnindimum Solder Mask Sliver Constraint: (0.047mm < 0.254mm) Between Pad U1-14(13.15mm,39.975mm) on Top Layer
Mnindimum Solder Mask Sliver Constraint: (0.047mm < 0.254mm) Between Pad U1-15(13.15mm,39.325mm) on Top Layer
Mnindimum Solder Mask Sliver Constraint: (0.047mm < 0.254mm) Between Pad U1-16(13.15mm,38.675mm) on Top Layer
Mnindimum Solder Mask Sliver Constraint: (0.047mm < 0.254mm) Between Pad U1-17(13.15mm,38.025mm) on Top Layer
Mnindimum Solder Mask Sliver Constraint: (0.047mm < 0.254mm) Between Pad U1-18(13.15mm,37.375mm) on Top Layer
Mnindimum Solder Mask Sliver Constraint: (0.047mm < 0.254mm) Between Pad U1-19(13.15mm,36.725mm) on Top Layer
Mnindimum Solder Mask Sliver Constraint: (0.047mm < 0.254mm) Between Pad U1-2(18.85mm,36.725mm) on Top Layer And

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

### Electrical Rules Check Report

Class | Document | Message Successful Compile for LightMod.PrjPcb
Tuesday 1 Dec 2020 5:21:21 PM | Page 1 of 1




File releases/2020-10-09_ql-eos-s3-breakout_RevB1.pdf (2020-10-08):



DESIGN NOTE:
Example text for informational
design notes .

Example text for critical
design notes.

Example text for cautionary

LAYOUT NOTE:
layout guidelines.

QL-EOS-S3-breakout.PrjPcb


QL-EOS-S3-breakout.PrjPcb


D 4 | G 6 I O _ 2 4
D 5 | I O _ 2 5

e Cut jumper JMP1 and provide 1.2-3.3V (?) reference v

mA max Note: Cu

ted as an FPG


QL-EOS-S3-breakout.PrjPcb



Design Rules Verification Report

Rule Violations
Power Plane Connect Rule(Relief Connect )(Expansion=0.508mm) (Conductor
Width=0.254mm)
Minimum Solder Mask Sliver (Gap=0.05mm) (InComponent('U1') and
IsPad),(InComponent('U1')

Minimum Solder Mask Sliver (Gap=0.148mm) (All),(All)
Minimum Solder Mask Sliver Constraint: (0.14mm < 0.148mm) Between Pad J1-A1/B12(12.115mm,29.19mm) on Top Layer
Minimum Solder Mask Sliver Constraint: (0.14mm < 0.148mm) Between Pad J1-A12/B1(5.665mm,29.198mm) on Top Layer
Minimum Solder Mask Sliver Constraint: (0.14mm < 0.148mm) Between Pad J1-A5(10.14mm,29.198mm) on Top Layer And
Minimum Solder Mask Sliver Constraint: (0.14mm < 0.148mm) Between Pad J1-A6(9.14mm,29.198mm) on Top Layer And
Minimum Solder Mask Sliver Constraint: (0.14mm < 0.148mm) Between Pad J1-A7(8.64mm,29.198mm) on Top Layer And
Minimum Solder Mask Sliver Constraint: (0.14mm < 0.148mm) Between Pad J1-A8(7.64mm,29.198mm) on Top Layer And


Silk To Solder Mask (Clearance=0.254mm) (IsPad),(All)
Silk To Solder Mask Clearance Constraint: (0.25mm < 0.254mm) Between Arc (13.165mm,11.5mm) on Top OverlayAnd Pad
Silk To Solder Mask Clearance Constraint: (0.25mm < 0.254mm) Between Arc (2.9mm,21.6mm) on Top OverlayAnd Pad
Silk To Solder Mask Clearance Constraint: (0.25mm < 0.254mm) Between Arc (4.615mm,9.5mm) on Top OverlayAnd Pad
Silk To Solder Mask Clearance Constraint: (0.211mm < 0.254mm) Between Arc (5.461mm,21.603mm) on Top OverlayAnd
Silk To Solder Mask Clearance Constraint: (0.225mm < 0.254mm) Between Pad C12-1(13.25mm,25.5mm) on Top Layer
ASinldk To Solder Mask Clearance Constraint: (0.242mm < 0.254mm) Between Pad C5-1(8.3mm,18.71mm) on Top Layer And
Silk To Solder Mask Clearance Constraint: (0.242mm < 0.254mm) Between Pad C5-1(8.3mm,18.71mm) on Top Layer And
Silk To Solder Mask Clearance Constraint: (0.233mm < 0.254mm) Between Pad P1-12(1.27mm,6.35mm) on Multi-Layer And
Silk To Solder Mask Clearance Constraint: (0.233mm < 0.254mm) Between Pad P1-13(1.27mm,3.81mm) on Multi-Layer And
Silk To Solder Mask Clearance Constraint: (0.233mm < 0.254mm) Between Pad P1-14(1.27mm,1.27mm) on Multi-Layer And
Silk To Solder Mask Clearance Constraint: (0.218mm < 0.254mm) Between Pad P2-12(16.51mm,6.35mm) on Multi-Layer
ASinldk To Solder Mask Clearance Constraint: (0.214mm < 0.254mm) Between Pad P2-13(16.51mm,3.81mm) on Multi-Layer
ASinldk To Solder Mask Clearance Constraint: (0.211mm < 0.254mm) Between Pad P2-14(16.51mm,1.27mm) on Multi-Layer
ASinldk To Solder Mask Clearance Constraint: (0.199mm < 0.254mm) Between Pad P3-1(3.81mm,1.27mm) on Multi-Layer And
Silk To Solder Mask Clearance Constraint: (0.2mm < 0.254mm) Between Pad P3-1(3.81mm,1.27mm) on Multi-Layer And
Silk To Solder Mask Clearance Constraint: (0.236mm < 0.254mm) Between Pad P3-3(8.89mm,1.27mm) on Multi-Layer And
Silk To Solder Mask Clearance Constraint: (0.248mm < 0.254mm) Between Pad P3-4(11.43mm,1.27mm) on Multi-Layer And
Silk To Solder Mask Clearance Constraint: (0.235mm < 0.254mm) Between Pad P3-5(13.97mm,1.27mm) on Multi-Layer And
Silk To Solder Mask Clearance Constraint: (0.248mm < 0.254mm) Between Pad P3-5(13.97mm,1.27mm) on Multi-Layer And
Silk To Solder Mask Clearance Constraint: (0.199mm < 0.254mm) Between Pad P4-1(3.81mm,3.81mm) on Multi-Layer And
Silk To Solder Mask Clearance Constraint: (0.2mm < 0.254mm) Between Pad P4-1(3.81mm,3.81mm) on Multi-Layer And
Silk To Solder Mask Clearance Constraint: (0.219mm < 0.254mm) Between Pad P4-2(6.35mm,3.81mm) on Multi-Layer And
Silk To Solder Mask Clearance Constraint: (0.236mm < 0.254mm) Between Pad P4-2(6.35mm,3.81mm) on Multi-Layer And
Silk To Solder Mask Clearance Constraint: (0.246mm < 0.254mm) Between Pad P4-3(8.89mm,3.81mm) on Multi-Layer And
Silk To Solder Mask Clearance Constraint: (0.236mm < 0.254mm) Between Pad P4-3(8.89mm,3.81mm) on Multi-Layer And
Silk To Solder Mask Clearance Constraint: (0.248mm < 0.254mm) Between Pad P4-4(11.43mm,3.81mm) on Multi-Layer And
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

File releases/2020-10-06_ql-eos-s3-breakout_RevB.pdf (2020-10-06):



DESIGN NOTE:
Example text for informational
design notes .

Example text for critical
design notes.

Example text for cautionary

LAYOUT NOTE:
layout guidelines.

QL-EOS-S3-breakout.PrjPcb


QL-EOS-S3-breakout.PrjPcb


D 4 | G 6 I O _ 2 4
D 5 | I O _ 2 5

e Cut jumper JMP1 and provide 1.2-3.3V (?) reference v

mA max Note: Cu

ted as an FPG


QL-EOS-S3-breakout.PrjPcb



Design Rules Verification Report

Rule Violations
Power Plane Connect Rule(Relief Connect )(Expansion=0.508mm) (Conductor
Width=0.254mm)


Minimum Solder Mask Sliver (Gap=0.254mm) (All),(All)
Minimum Solder Mask Sliver Constraint: (0.017mm < 0.254mm) Between Pad C10-1(10mm,24.89mm) on Bottom Layer And
Minimum Solder Mask Sliver Constraint: (0.017mm < 0.254mm) Between Pad C1-1(10.81mm,20mm) on Bottom Layer And
Minimum Solder Mask Sliver Constraint: (0.178mm < 0.254mm) Between Pad C1-1(10.81mm,20mm) on Bottom Layer And
Minimum Solder Mask Sliver Constraint: (0.177mm < 0.254mm) Between Pad C1-1(10.81mm,20mm) on Bottom Layer And
Minimum Solder Mask Sliver Constraint: (0.017mm < 0.254mm) Between Pad C11-1(4.015mm,12.625mm) on Top Layer
Minimum Solder Mask Sliver Constraint: (0.178mm < 0.254mm) Between Pad C1-2(11.59mm,20mm) on Bottom Layer And
Minimum Solder Mask Sliver Constraint: (0.229mm < 0.254mm) Between Pad C12-1(13.25mm,25.5mm) on Top Layer And
Minimum Solder Mask Sliver Constraint: (0.223mm < 0.254mm) Between Pad C12-1(13.25mm,25.5mm) on Top Layer And
Minimum Solder Mask Sliver Constraint: (0.228mm < 0.254mm) Between Pad C12-1(13.25mm,25.5mm) on Top Layer And
Minimum Solder Mask Sliver Constraint: (0.223mm < 0.254mm) Between Pad C12-2(11.95mm,25.5mm) on Top Layer And
Minimum Solder Mask Sliver Constraint: (0.017mm < 0.254mm) Between Pad C2-1(11.81mm,22.1mm) on Bottom Layer
PaMindimum Solder Mask Sliver Constraint: (0.017mm < 0.254mm) Between Pad C4-1(11.89mm,16.8mm) on Top Layer And
PaMindimum Solder Mask Sliver Constraint: (0.017mm < 0.254mm) Between Pad C5-1(8.3mm,18.71mm) on Top Layer And
PaMindimum Solder Mask Sliver Constraint: (0.212mm < 0.254mm) Between Pad C5-1(8.3mm,18.71mm) on Top Layer And
PaMindimum Solder Mask Sliver Constraint: (0.227mm < 0.254mm) Between Pad C5-1(8.3mm,18.71mm) on Top Layer And
PaMindimum Solder Mask Sliver Constraint: (0.227mm < 0.254mm) Between Pad C5-2(8.3mm,19.49mm) on Top Layer And
PaMindimum Solder Mask Sliver Constraint: (0.212mm < 0.254mm) Between Pad C5-2(8.3mm,19.49mm) on Top Layer And
PaMindimum Solder Mask Sliver Constraint: (0.017mm < 0.254mm) Between Pad C6-1(14.19mm,20.4mm) on Top Layer And
PaMindimum Solder Mask Sliver Constraint: (0.017mm < 0.254mm) Between Pad C7-1(12.59mm,21.2mm) on Bottom Layer
Minimum Solder Mask Sliver Constraint: (0.14mm < 0.254mm) Between Pad J1-A1/B12(12.115mm,29.19mm) on Top Layer
Minimum Solder Mask Sliver Constraint: (0.176mm < 0.254mm) Between Pad J1-A1/B12(12.115mm,29.19mm) on Top
Minimum Solder Mask Sliver Constraint: (0.176mm < 0.254mm) Between Pad J1-A12/B1(5.665mm,29.198mm) on Top
Minimum Solder Mask Sliver Constraint: (0.14mm < 0.254mm) Between Pad J1-A5(10.14mm,29.198mm) on Top Layer And
Minimum Solder Mask Sliver Constraint: (0.14mm < 0.254mm) Between Pad J1-A6(9.14mm,29.198mm) on Top Layer And
Minimum Solder Mask Sliver Constraint: (0.14mm < 0.254mm) Between Pad J1-A7(8.64mm,29.198mm) on Top Layer And
Minimum Solder Mask Sliver Constraint: (0.14mm < 0.254mm) Between Pad J1-A8(7.64mm,29.198mm) on Top Layer And
Minimum Solder Mask Sliver Constraint: (0.203mm < 0.254mm) Between Pad J1-A9/B4(6.44mm,29.198mm) on Top Layer
Minimum Solder Mask Sliver Constraint: (0.147mm < 0.254mm) Between Pad R10-1(13.2mm,15.4mm) on Top Layer And
PaMindimum Solder Mask Sliver Constraint: (0.147mm < 0.254mm) Between Pad R1-1(10.8mm,27.1mm) on Top Layer And
PaMindimum Solder Mask Sliver Constraint: (0.247mm < 0.254mm) Between Pad R1-1(10.8mm,27.1mm) on Top Layer And
PaMindimum Solder Mask Sliver Constraint: (0.147mm < 0.254mm) Between Pad R11-1(14.2mm,15.4mm) on Top Layer And
PaMindimum Solder Mask Sliver Constraint: (0.247mm < 0.254mm) Between Pad R1-2(10.8mm,26.3mm) on Top Layer And
PaMindimum Solder Mask Sliver Constraint: (0.147mm < 0.254mm) Between Pad R12-1(14.2mm,13.5mm) on Top Layer And
PaMindimum Solder Mask Sliver Constraint: (0.147mm < 0.254mm) Between Pad R13-1(7.4mm,18.7mm) on Top Layer And
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

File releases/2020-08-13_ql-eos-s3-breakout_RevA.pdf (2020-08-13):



DESIGN NOTE:
Example text for informational
design notes .

Example text for critical
design notes.

Example text for cautionary

LAYOUT NOTE:
layout guidelines.

QL-EOS-S3-breakout.PrjPcb


QL-EOS-S3-breakout.PrjPcb


Design intent:
-Low-cost, minimum viable ARM+FPGA design that is breadboard compatable
-Footprint, power, UART pin compatibility with Teensy 3.2.
-All pins on Bank A placed in a group, because they can have their IO voltage set with a
reference
-Bootstrap, SPI flash, and reset pins placed in non-breadboardable location to avoid
inadvertant interference with application circuit
-Pins with multiple IO functions preferred over FPGA only pins
-Pins in ascending order by FPGA IO number when possible

Useful connections:
-Jumper VCCIOA to 3.3V if the connection was cut
-Jumper SYS_RSTn to GND to put processor in reset for external SPI Flash programming
-Jumper IO_19 to 3.3V to enable JTAG SWD on boot

I/O Bank A reference voltage Cut jumper JMP1 and provide 1.2-3.3V (?) reference voltage on VCCIOA pin

Status indication and feedback

IO_8: SWD pin assignment: pull down for 14/15 (default), up for 44/45
IO_8/IO_9: High speed oscillator selection; both pulled up for external
oscillator, otherwise internal oscillator
IO_19: Enable SWD: pull down to disable, up to enable
IO_20: Boot mode: pull down for host (boot from SPI flash), pull up for

Note: Cut JMP2 to power board from VIN pin

Note: USER_LED and USER_BUTTON must be on ARM GPIO pins

Program memory loaded from SPI flash at boot

USB is impletented as an FPGA soft core

TODO: Use SPI flash part from reference board

QL-EOS-S3-breakout.PrjPcb


QL-EOS-S3-breakout.PrjPcb



Design Rules Verification Report

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

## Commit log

2020-08-04 Rough design
    [QL-EOS-S3-breakout.PcbDoc, QL-EOS-S3-breakout.PrjPcb, S3 base.SchDoc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]
2020-08-08 Updated pinout, mostly routed
    [QL-EOS-S3-breakout.PcbDoc, [02] Block Diagram.SchDoc, [03] SOC.SchDoc]
2020-08-12 Mostly routed
    -Change wires to 6/6mil tolerace (power lines to 16mil)
    -Change BGA vias to .15 (need to confirm process)
    TODO:
    -Replace 4.7uF caps on back with 0402 version
    -Change polyfuse footprint + place
    -make footprint for cuttable jumpers
    [QL-EOS-S3-breakout.PcbDoc, QL-EOS-S3-breakout.PrjPcb, [03] SOC.SchDoc]
2020-08-13 RevA releases, then some small fixes
    Notes:
    -Need to fix three vias with .127mm diameter in RevA
    -Need to verify pinout changes against toolchain
    [2020-08-13_ql-eos-s3-breakout_RevA BOM.xlsx, 2020-08-13_ql-eos-s3-breakout_RevA Pick Place.csv, QL-EOS-S3-breakout.PcbDoc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]
2020-08-13 Update board render
2020-10-06 RevB PCB
    - Move pin IO_43 to header, shift other pins and drop ground
    - Add ground isolation around analog lines
    [QL-EOS-S3-breakout.PcbDoc, QL-EOS-S3-breakout.PrjPcb, [01] cover page.SchDoc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]
2020-10-06 Add RevB release files, update documentation
    [2020-10-06_ql-eos-s3-breakout_RevB BOM.xlsx, 2020-10-06_ql-eos-s3-breakout_RevB Pick Place.csv]
2020-10-08 RevB1: increase BGA pad size to .25mm
    [2020-10-09_ql-eos-s3-breakout_RevB1 BOM.xlsx, 2020-10-09_ql-eos-s3-breakout_RevB1 Pick Place.csv, QL-EOS-S3-breakout.PcbDoc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]
2020-10-16 Add panel stencil
    [2020-10-16 ql-eos-s3-breakout stencil.gtp]
2020-11-17 New connection drawings
    [debug pins.ods]
2020-11-17 Updates from RevB testing
    * Replace C5 with 4.7uF cap for better reset behaviour
    * DNP R10 (need to pull down IO_8)
    * Break out IO_15, replacing ADC1
    * Switch to default pins for UART, JTAG
    * Remove unused strapping resistors (pins are availabe on P5)
    * Re-order pins on P1 and P2 to be in order again
    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
    [QL-EOS-S3-breakout.PcbDoc, QL-EOS-S3-breakout.PrjPcb, [03] SOC.SchDoc]
2020-11-18 Changes for RevC:
    * Remove ground planes on top and bottom layers
    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
    [QL-EOS-S3-breakout.PcbDoc, QL-EOS-S3-breakout.PrjPcb, [03] SOC.SchDoc]
2020-11-23 Changes for RevC
    PCB:
    - Add silkscreen identifiers for RESET, USER buttons
    - Add silkscreen placement rectangle around QL-EOS-S3 part
    Schematic:
    - Update pin function list
    [QL-EOS-S3-breakout.PcbDoc, [03] SOC.SchDoc]
2020-11-23 Fix voltage range
2020-11-24 Remove I2C, since it's not accessable by the ARM
    [QL-EOS-S3-breakout.PcbDoc, [03] SOC.SchDoc]
2020-12-01 Fix pin numbers in FTDI drawing
2020-12-01 Add example dev board
    [2020-12-01_LightsAway_RevA BOM.xlsx, 2020-12-01_LightsAway_RevA Pick Place.csv, 2020-12-01_LightsAway_RevA.step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]
2021-06-04 Preliminary release files for RevC
    [2021-06-04_ql-eos-s3-breakout_RevC BOM.xlsx, 2021-06-04_ql-eos-s3-breakout_RevC Pick Place.csv, QL-EOS-S3-breakout.PcbDoc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]
